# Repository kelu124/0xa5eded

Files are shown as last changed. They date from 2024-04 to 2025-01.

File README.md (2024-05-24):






 





# An 8-bit, 100Msps ADC standalone pHAT

aka 0xA5EDED == sha1(pHATrick)

# Description

An 8-bit, 125Msps ADC standalone pHAT

More? @TODO

# What

__Beware - these need to be updated with actual assembled board. v2 includes sees top going bottom and vice versa.__

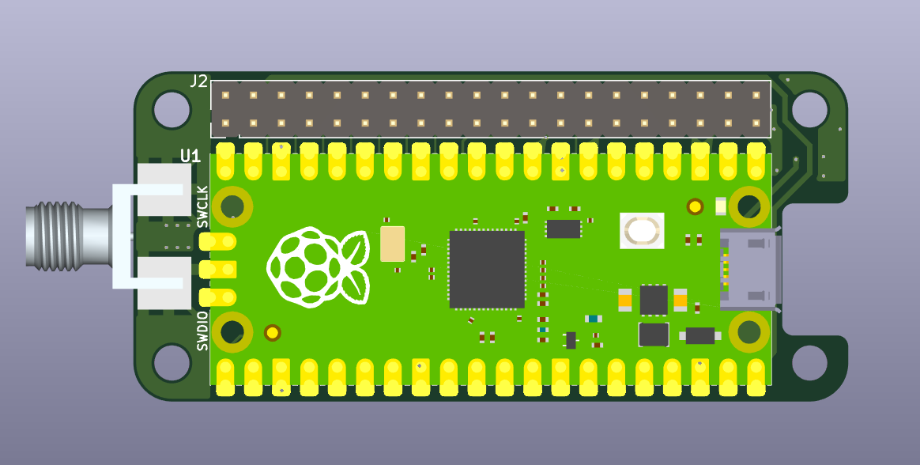
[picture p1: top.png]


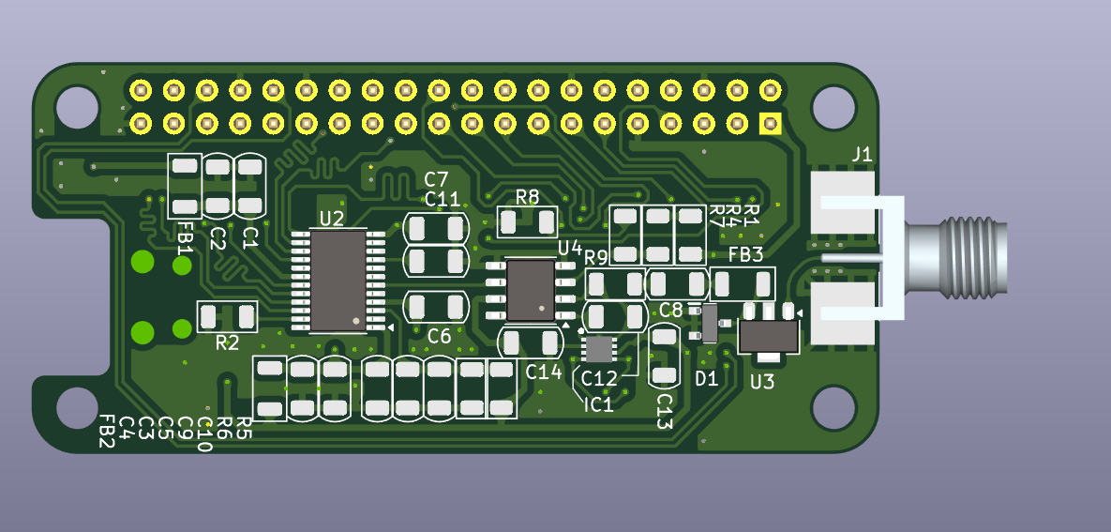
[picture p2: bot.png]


# Acquisition of a square/sine wave

Signal coming out of a cheap DSO, should be around square, 4MHz

### Acquisition 

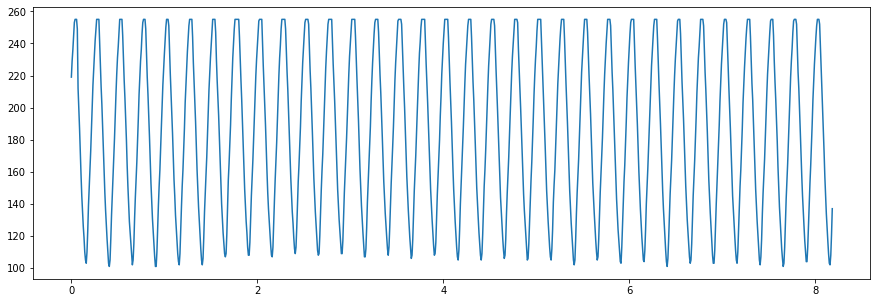
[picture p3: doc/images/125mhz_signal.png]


### Spectrum of a square wave at 125Msps

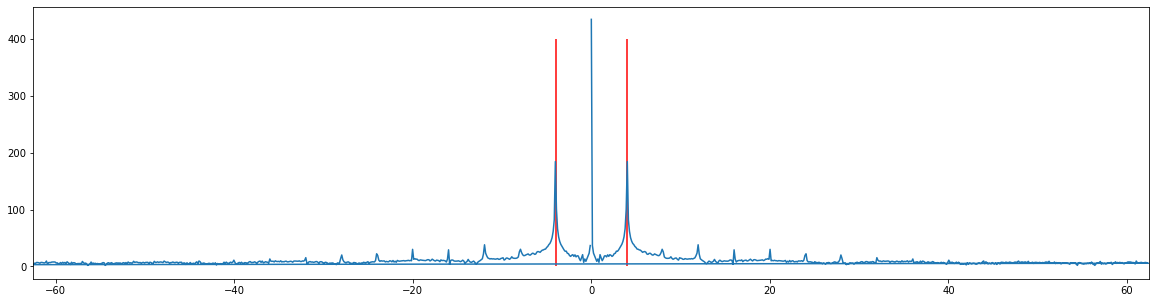
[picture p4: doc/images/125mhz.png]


# Changes from v1

* Remove i2c to something simpler - MCP40D17T
* Let user choose offset or not
* Check OPAMP capa to get a 60MHz cutoff
* BAV / MD0100 to be removed
* Putting the rp2040 under the board, to expose the beautiful art to users

# License

This work is based a previous TAPR exploration, the [pic0rick project](https://github.com/kelu124/pic0rick/) - these open hardware and software, developped with open-source elements as much as possible.

Copyright Luc Jonveaux (kelu124@gmail.com) 2024

* The hardware is licensed under TAPR Open Hardware License (www.tapr.org/OHL)
* The software components are free software: you can redistribute it and/or modify it under the terms of the GNU General Public License as published by the Free Software Foundation, either version 3 of the License, or (at your option) any later version.
* The documentation is licensed under a [Creative Commons Attribution-ShareAlike 3.0 Unported License](http://creativecommons.org/licenses/by-sa/3.0/).

## Disclaimer

This project is distributed WITHOUT ANY EXPRESS OR IMPLIED WARRANTY, INCLUDING OF MERCHANTABILITY, SATISFACTORY QUALITY AND FITNESS FOR A PARTICULAR PURPOSE.

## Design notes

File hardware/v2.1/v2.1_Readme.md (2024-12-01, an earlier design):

# v2.1 : Remarks after prod

## Issues

Prod done on Nov 4th 2024

* Issues with TLV271 (particularily the GND pin)
  * Quick fix by removing TLV271 
  * and shorting pin 3 and 4 (VREF of ADC to output of U10)

* 40pins header issues:
  * Free header pins 26/17 (used in RPi by ID EEPROM), move to other pins
  * Wrong GND pin: move GND from pin 22 to pin 20 (22 isn't ground)
  * Rename GPIO24/GPIO25 on schematics (to the 2 other ADCs)
  * A0 to be to header too

* SDA and SCL are switched. Needs to be corrected.
* Add pullups to the SDA lines, to 3.3V.

## Passive sizes

* Make R16, R8 and R9 1206-sized

## TO ADD

Marking to OSHWA
- https://certification.oshwa.org/fr000022.html
-

## ADC

* Return to 10b ADC : ADC10080

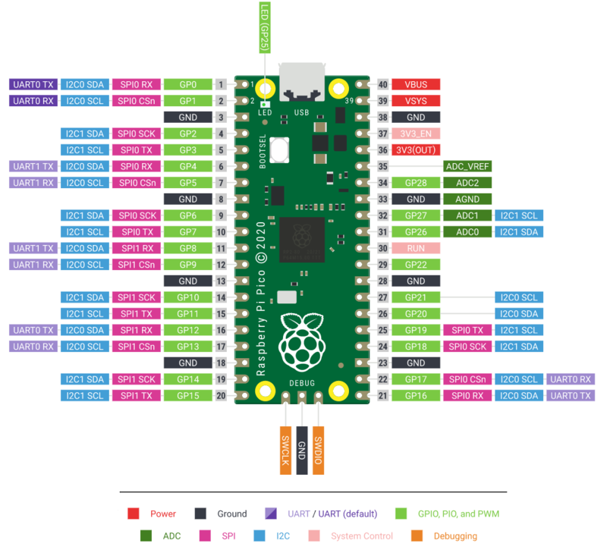
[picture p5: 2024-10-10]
hardware/v2.2b/datasheet/raspberry_pi_Pico-R3-Pinout-narrow.png

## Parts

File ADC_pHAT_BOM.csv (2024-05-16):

Reference | Value | Datasheet | Footprint | Qty | DNP
C1,C3,C4 | 22uF | ~ | Capacitor_SMD_AKL:C_1206_3216Metric | 3
C2,C5,C6,C7,C10,C11,C13,C14 | 100nF | ~ | Capacitor_SMD_AKL:C_1206_3216Metric | 8
C8,C9 | 1uF | ~ | Capacitor_SMD_AKL:C_1206_3216Metric | 2
C12 | 33pF | ~ | Capacitor_SMD_AKL:C_1206_3216Metric | 1
D1 | BAV99-7-F | https://www.diodes.com/assets/Datasheets/ds12007.pdf | SamacSys_Parts:SOT95P240X120-3N | 1
FB1,FB2,FB3 | FerriteBead_Small | ~ | Inductor_SMD_AKL:L_1206_3216Metric | 3
IC1 | MAX5395LATA+T | https://pdfserv.maximintegrated.com/en/ds/MAX5395.pdf | SamacSys_Parts:SON50P200X200X80-9N-D | 1
J1 | Conn_Coaxial | ~ | ICTAMKY_V8:AMPHENOL_132357-11 | 1
J2 | Conn_02x20_Odd_Even | ~ | Connector_PinHeader_2.54mm:PinHeader_2x20_P2.54mm_Vertical | 1
R1,R5,R7 | 110 | ~ | Resistor_SMD_AKL:R_1206_3216Metric | 3
R2 | 10K | ~ | Resistor_SMD_AKL:R_1206_3216Metric | 1
R4,R6 | 220 | ~ | Resistor_SMD_AKL:R_1206_3216Metric | 2
R8 | 56 | ~ | Resistor_SMD_AKL:R_1206_3216Metric | 1
R9 | 1K | ~ | Resistor_SMD_AKL:R_1206_3216Metric | 1
U1 | Pico |  | ICTAMKY_V8:RPi_Pico_SMD | 1
U2 | ADC08100CIMTCX/NOPB(TSSOP-24) |  | Package_SO:TSSOP-24_4.4x7.8mm_P0.65mm | 1
U3 | MD0100N8-G | MD0100N8-G | Package_TO_SOT_SMD:SOT-89-3 | 1
U4 | LTC6228xS8 | https://www.analog.com/media/en/technical-documentation/data-sheets/LTC6228-6229.pdf | Package_SO:SO-8_3.9x4.9mm_P1.27mm | 1

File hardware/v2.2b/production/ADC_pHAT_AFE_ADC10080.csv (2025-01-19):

Id | Designator | Footprint | Quantity | Designation | Supplier and ref
1 | U2 | SOT-23 | 1 | LM4040DBZ-2.0
2 | R2,R19,R18,R17 | R_0603_1608Metric | 4 | 1K
3 | C15 | C_0603_1608Metric | 1 | 4.7u
4 | D3,D2,D1 | D_0603_1608Metric | 3 | D
5 | C13,C8,C12,C14 | C_0603_1608Metric | 4 | 2.2u
6 | R11,R14,R13 | R_0603_1608Metric | 3 | 100
7 | C9,C3,C7,C2,C6,C10,C5 | R_0603_1608Metric | 7 | 100nF
8 | R3,R1 | R_0603_1608Metric | 2 | 87k
9 | R5,R6 | R_0603_1608Metric | 2 | 10K
10 | U8 | SOT-23-6 | 1 | DAC5571
11 | U3 | WSON-12-1EP_3x2mm_P0.5mm_EP1x2.65_ThermalVias | 1 | LM27762
12 | J3 | AMPHENOL_132357-11-MOD | 1 | Conn_Coaxial
13 | FB2,FB1 | L_1206_3216Metric | 2 | FerriteBead_Small
14 | U4 | MSOP-10_3x3mm_P0.5mm | 1 | ADG621
15 | C18 | C_0603_1608Metric | 1 | 1p
16 | IC1 | SOP65P640X120-28N | 1 | ADC10080CIMT_NOPB
17 | C1,C4 | R_0603_1608Metric | 2 | 4.7uF
18 | R8 | R_1206_3216Metric | 1 | 47
19 | C23 | C_0603_1608Metric | 1 | 160p
20 | R12 | R_0603_1608Metric | 1 | 680k
21 | C21 | C_0603_1608Metric | 1 | 10n
22 | R7,R4 | R_0603_1608Metric | 2 | 50K
23 | C22 | C_0603_1608Metric | 1 | 6.8p
24 | C17,C20,C19,C16,C24 | C_0603_1608Metric | 5 | 100n
25 | R9,R16 | R_1206_3216Metric | 2 | 100
26 | J1 | PinHeader_1x02_P1.00mm_Vertical_SMD_Pin1Left | 1 | Conn_01x02_Male
27 | U6 | SOT-23-5 | 1 | TPH2501
28 | R10 | R_0603_1608Metric | 1 | 680
29 | U5 | SOT-23-5 | 1 | OPA830
30 | R15 | R_0603_1608Metric | 1 | 100k
31 | U7 | SOT-23-5 | 1 | LMH6629
32 | J2 | PinSocket_2x20_P2.54mm_Vertical | 1 | Conn_02x20_Odd_Even
33 | U1 | RPi_Pico_SMD | 1 | Pico

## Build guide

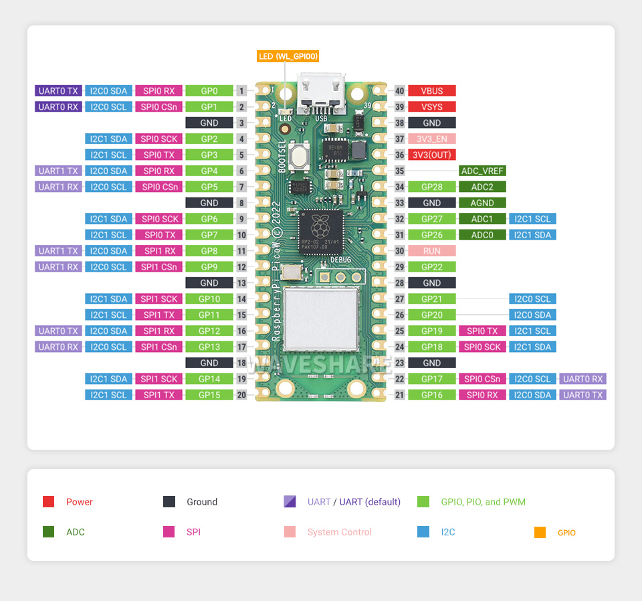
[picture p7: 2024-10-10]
hardware/v2.2b/datasheet/Raspberry_Pi_Pico_W_Manual01.jpg

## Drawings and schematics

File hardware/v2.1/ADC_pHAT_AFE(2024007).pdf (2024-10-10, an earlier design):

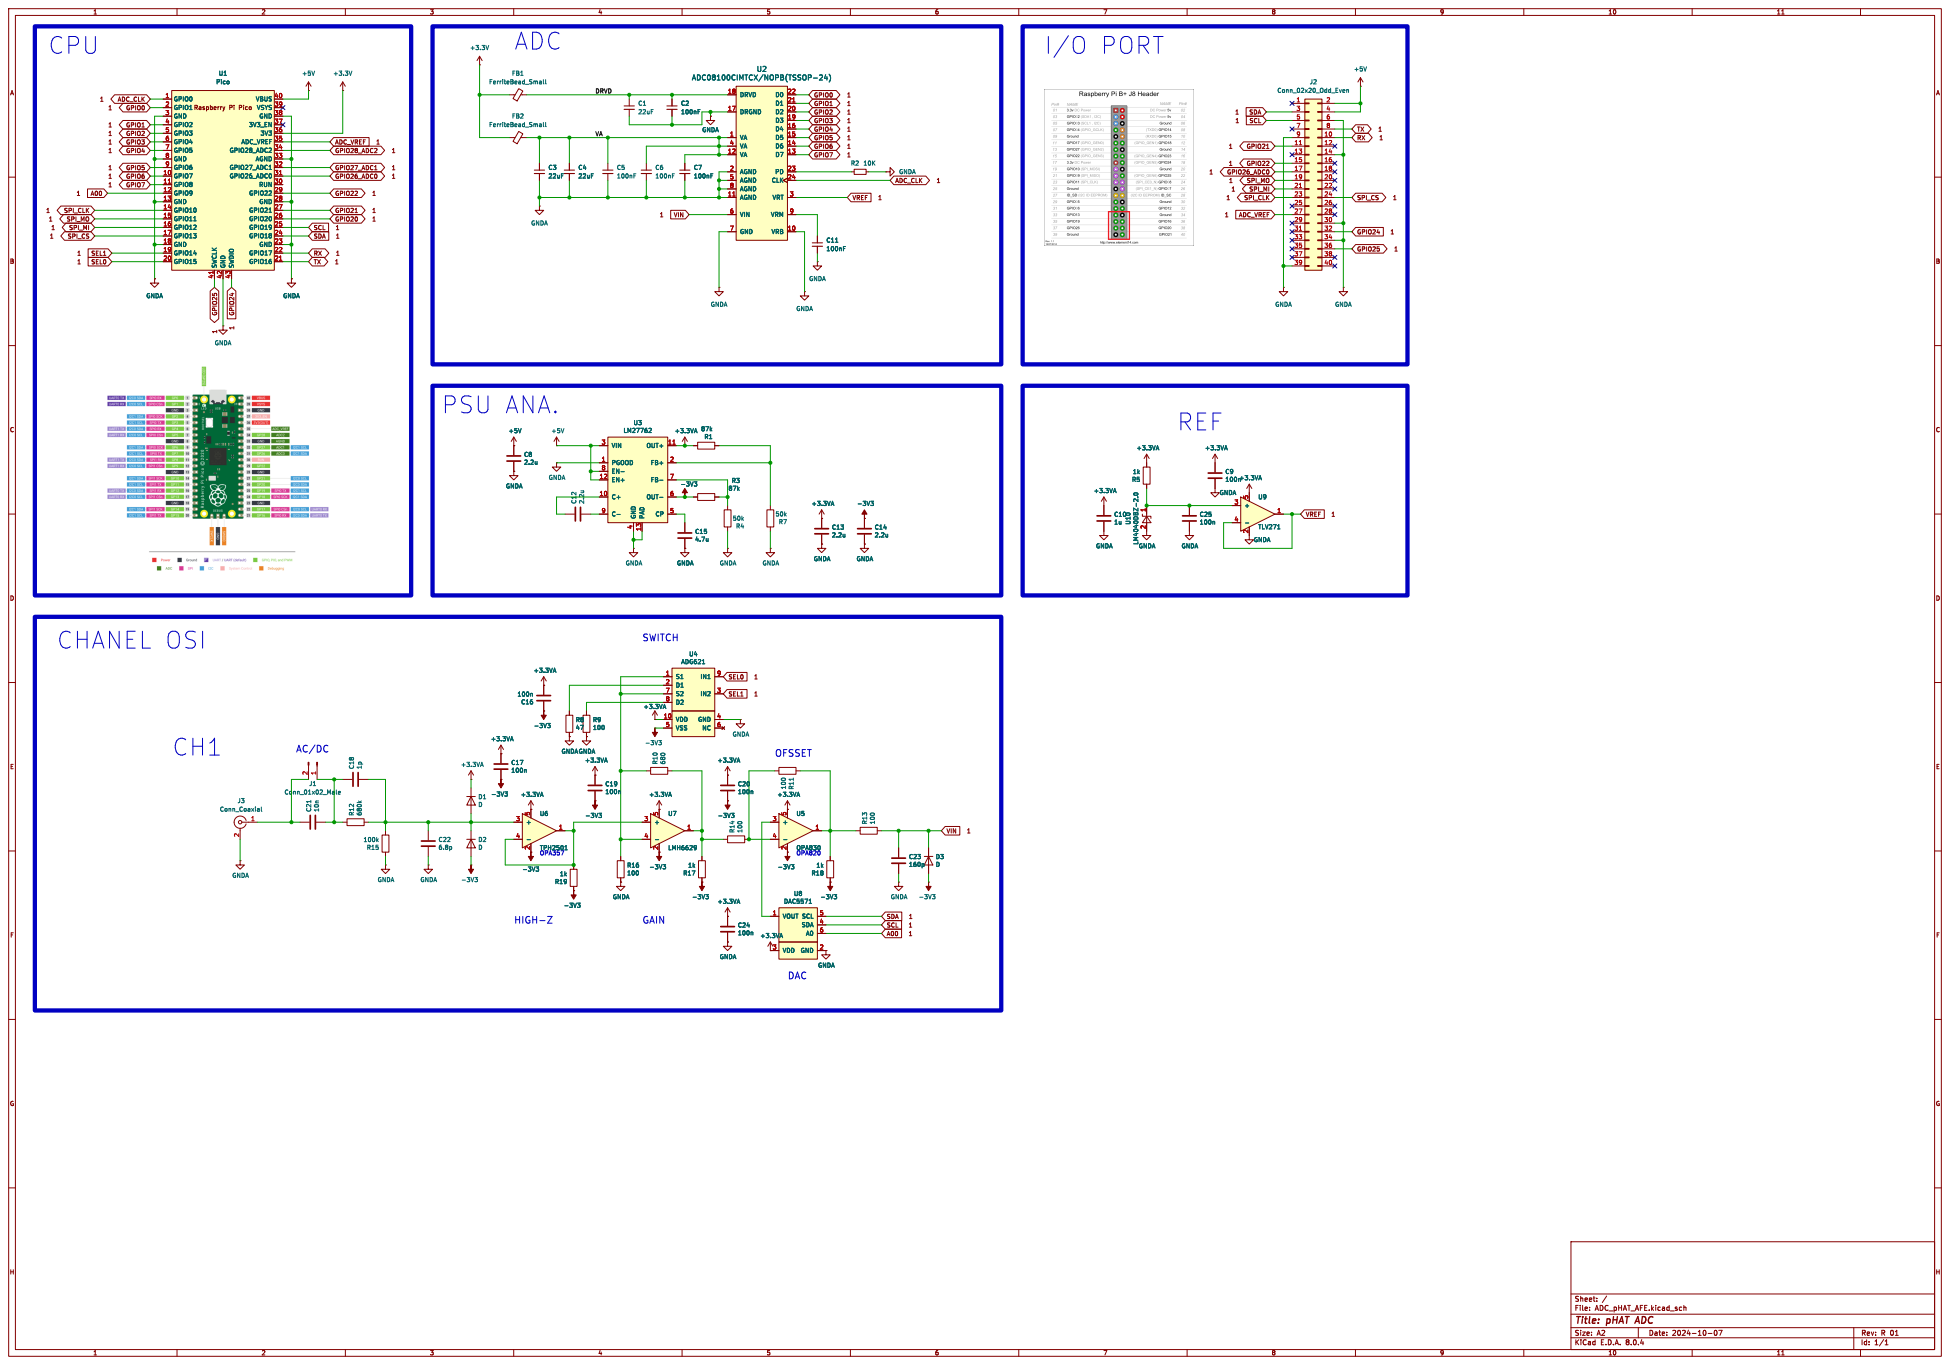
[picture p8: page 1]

4 CP 5 OUT- 6 FB- 7 EN- 8 C- 9 GNDA U1 Pico GPIO0 1 GPIO7 10 GPIO8 11 GPIO9 12 GND 13 GPIO10 14 GPIO11 15 GPIO12 16 GPIO13 17 GND 18 GPIO14 19 GPIO1 2 GPIO15 20 GPIO16 21 GPIO17 22 GND 23 GPIO18 24 GPIO19 25 GPIO20 26 GPIO21 27 GND 28 GPIO22 29 GND 3 RUN 30 GPIO26_ADC0 31 GPIO27_ADC1 32 AGND 33 GPIO28_ADC2 34 ADC_VREF 35

4 CP 5 OUT- 6 FB- 7 EN- 8 C- 9 U3

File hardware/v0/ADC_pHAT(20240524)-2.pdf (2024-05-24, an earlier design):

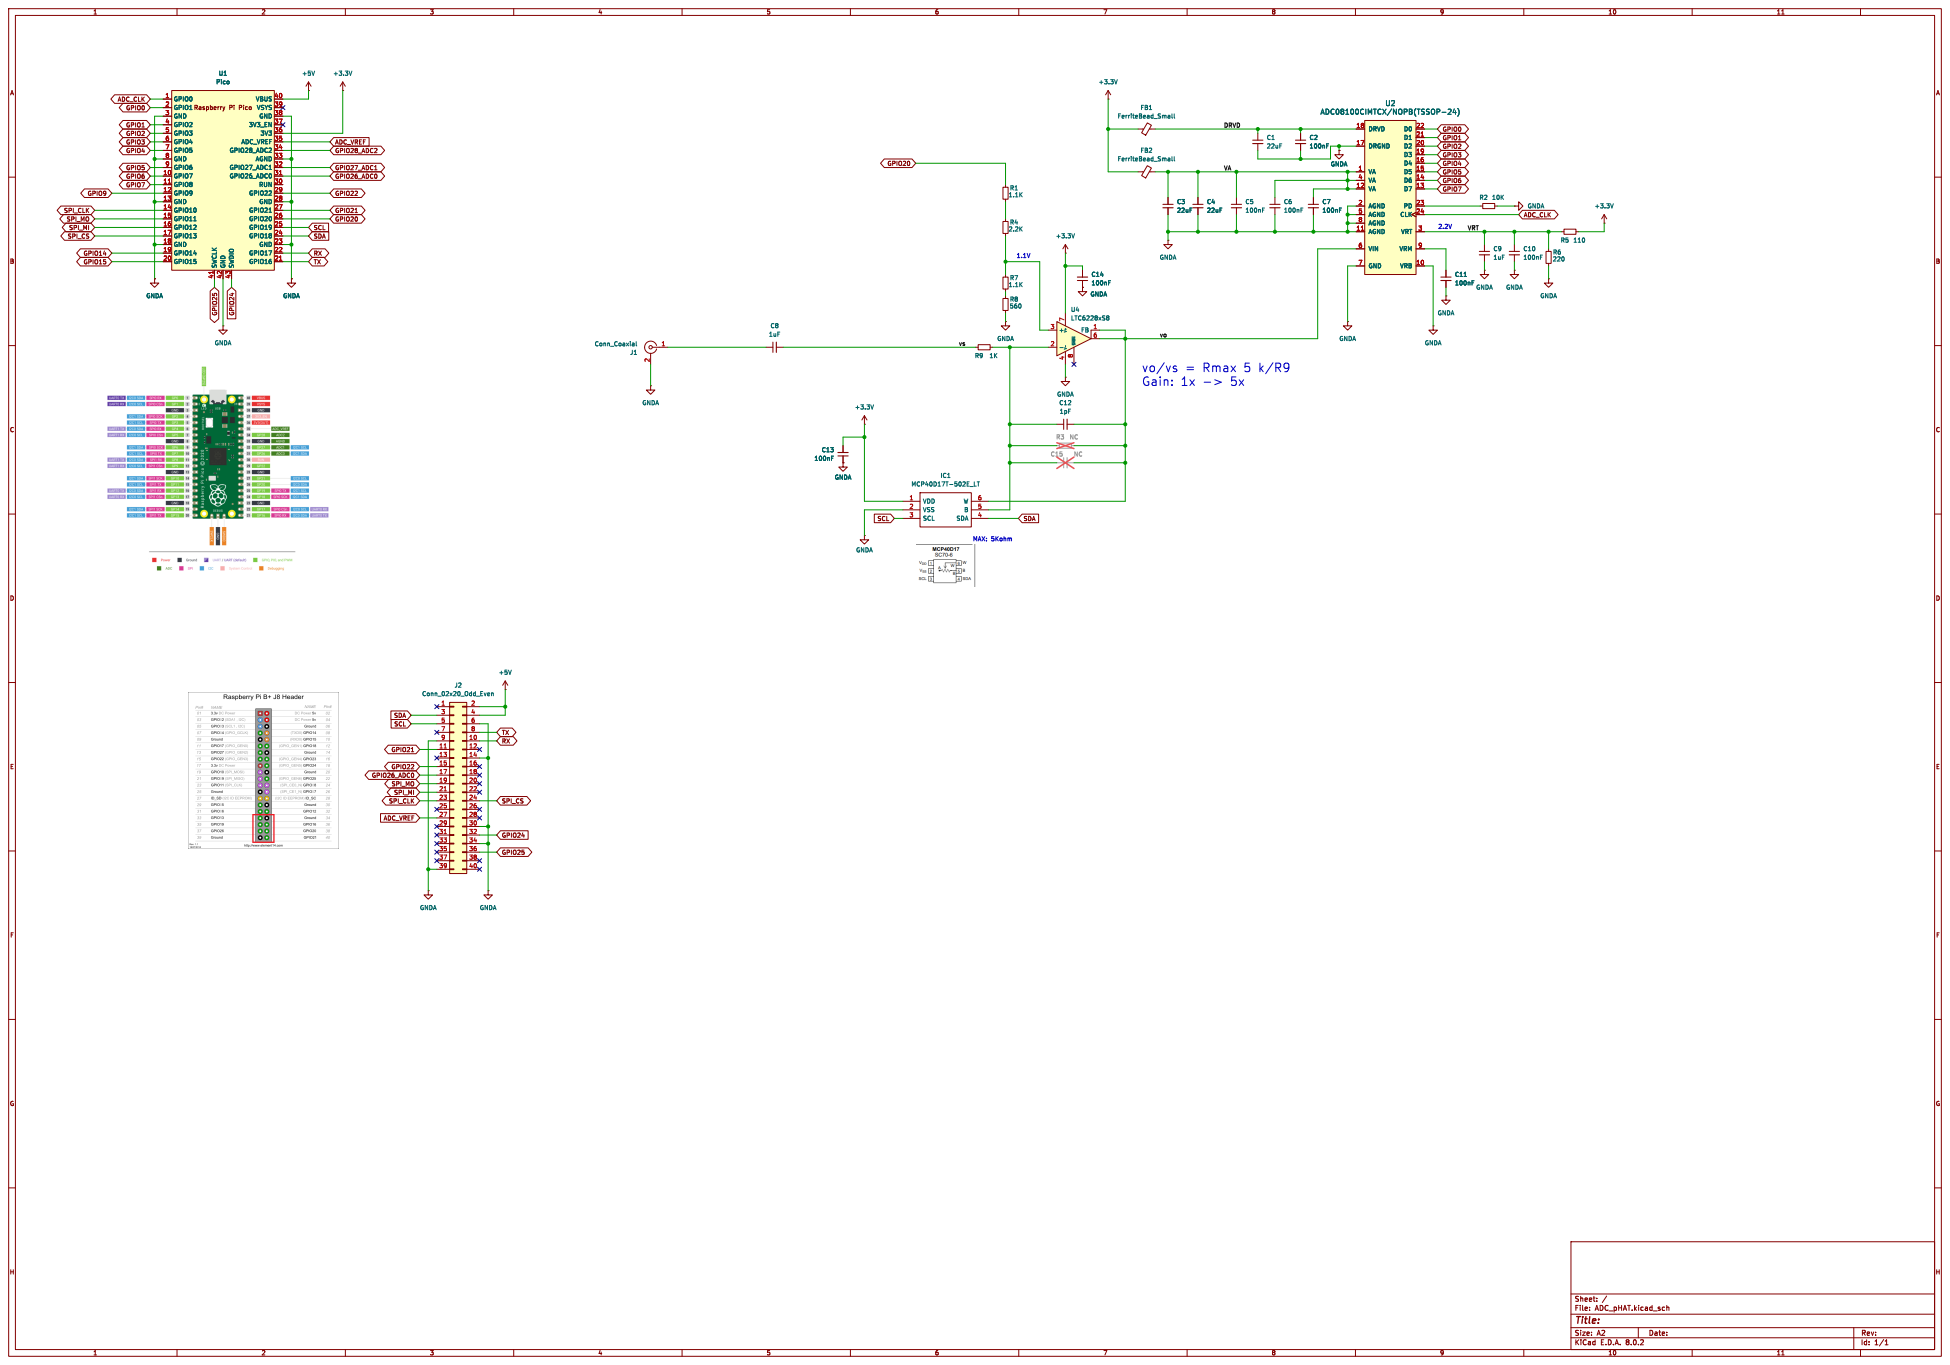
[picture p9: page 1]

220 GNDA GNDA GNDA GNDA

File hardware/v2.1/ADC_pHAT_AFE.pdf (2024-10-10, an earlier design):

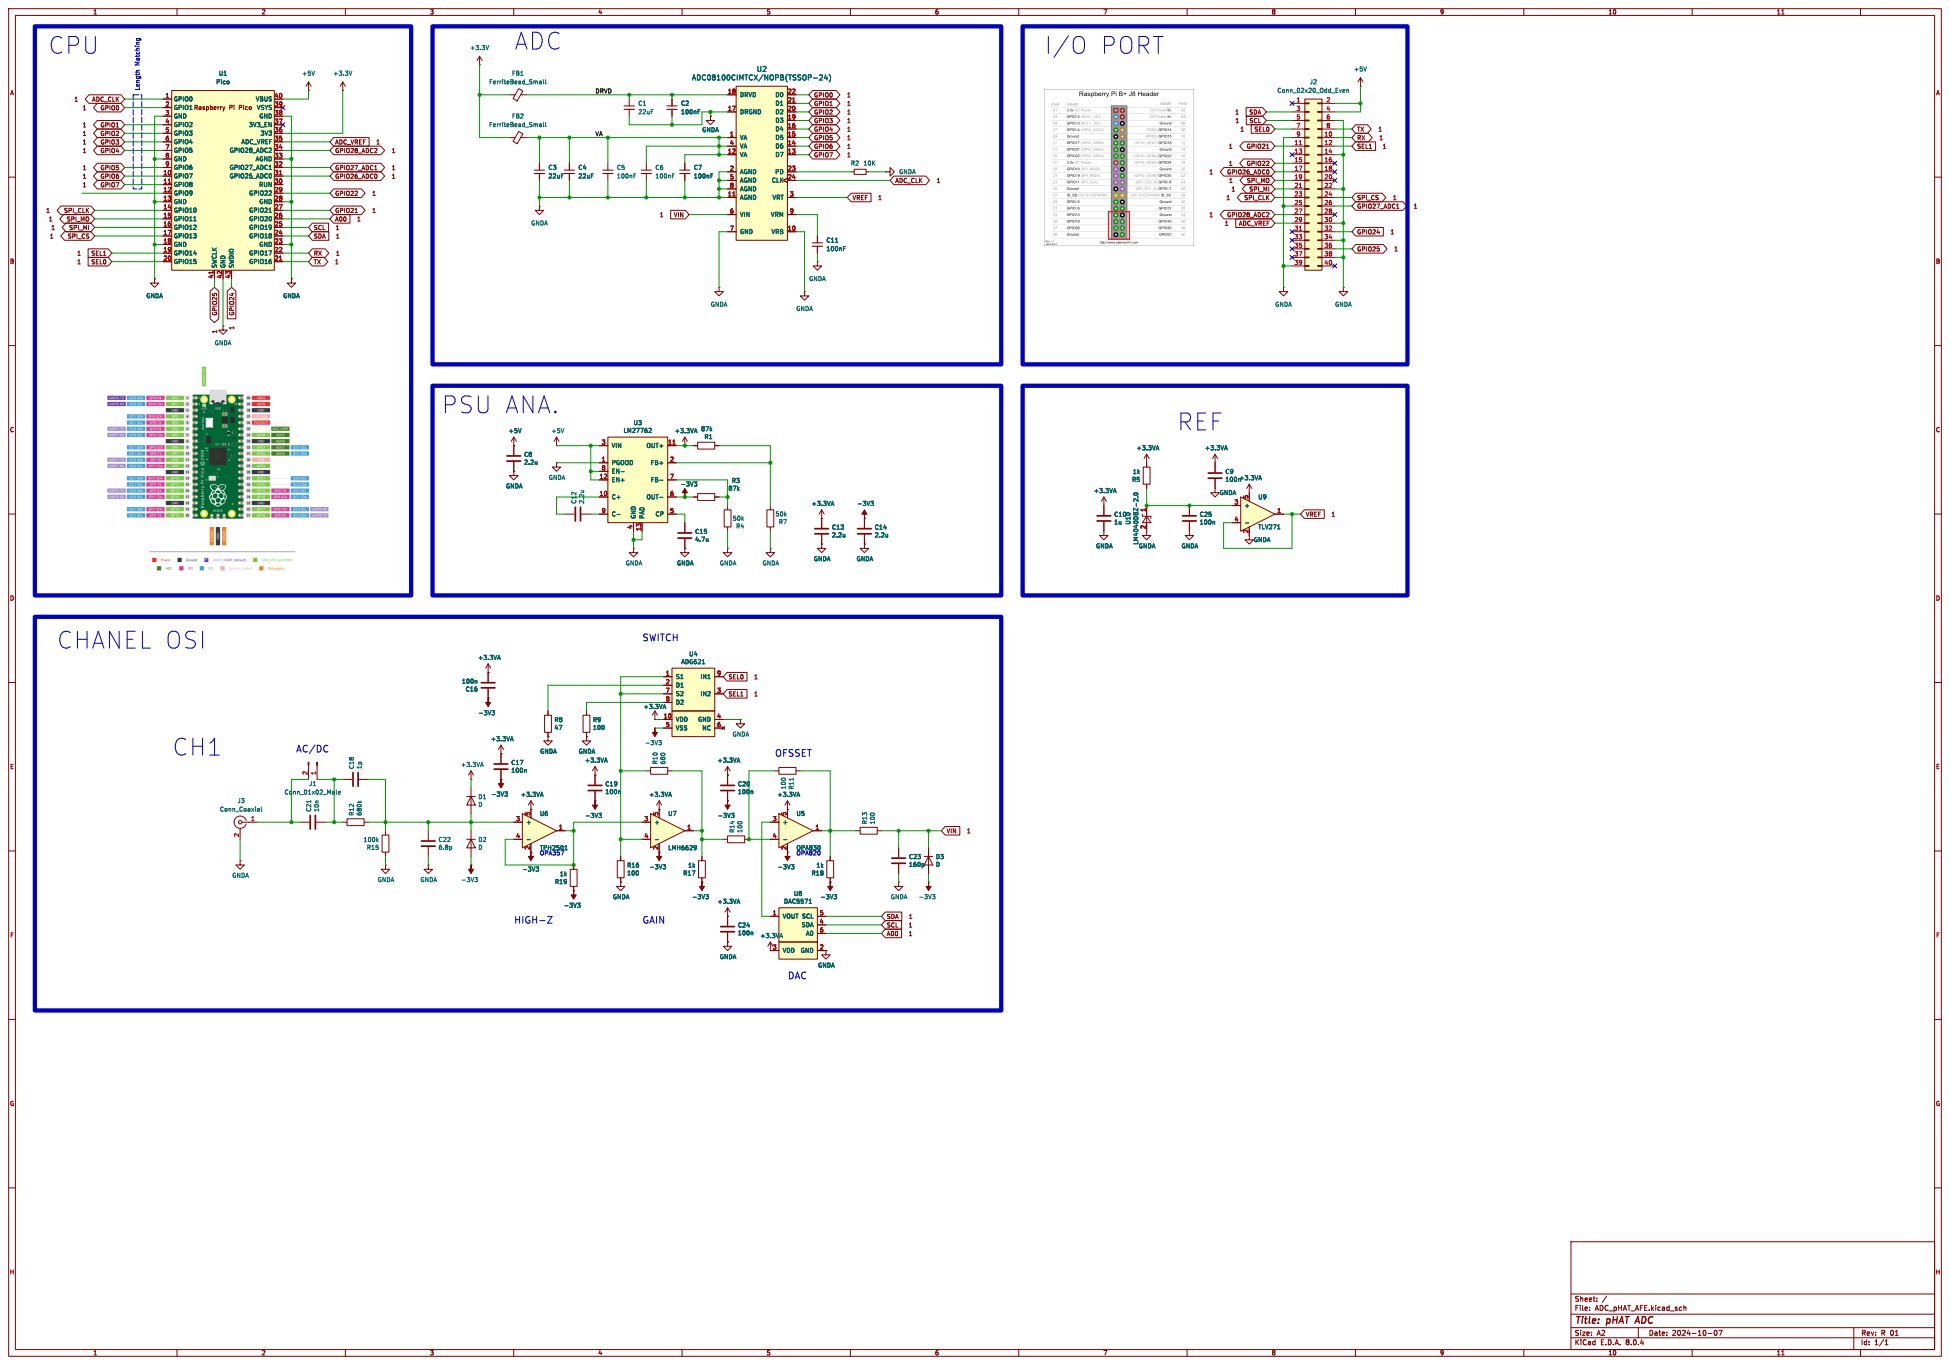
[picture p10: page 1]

4 CP 5 OUT- 6 FB- 7 EN- 8 C- 9 U3

4 CP 5 OUT- 6 FB- 7 EN- 8 C- 9 U4 ADG621 S1 1 VDD 10 D1 2

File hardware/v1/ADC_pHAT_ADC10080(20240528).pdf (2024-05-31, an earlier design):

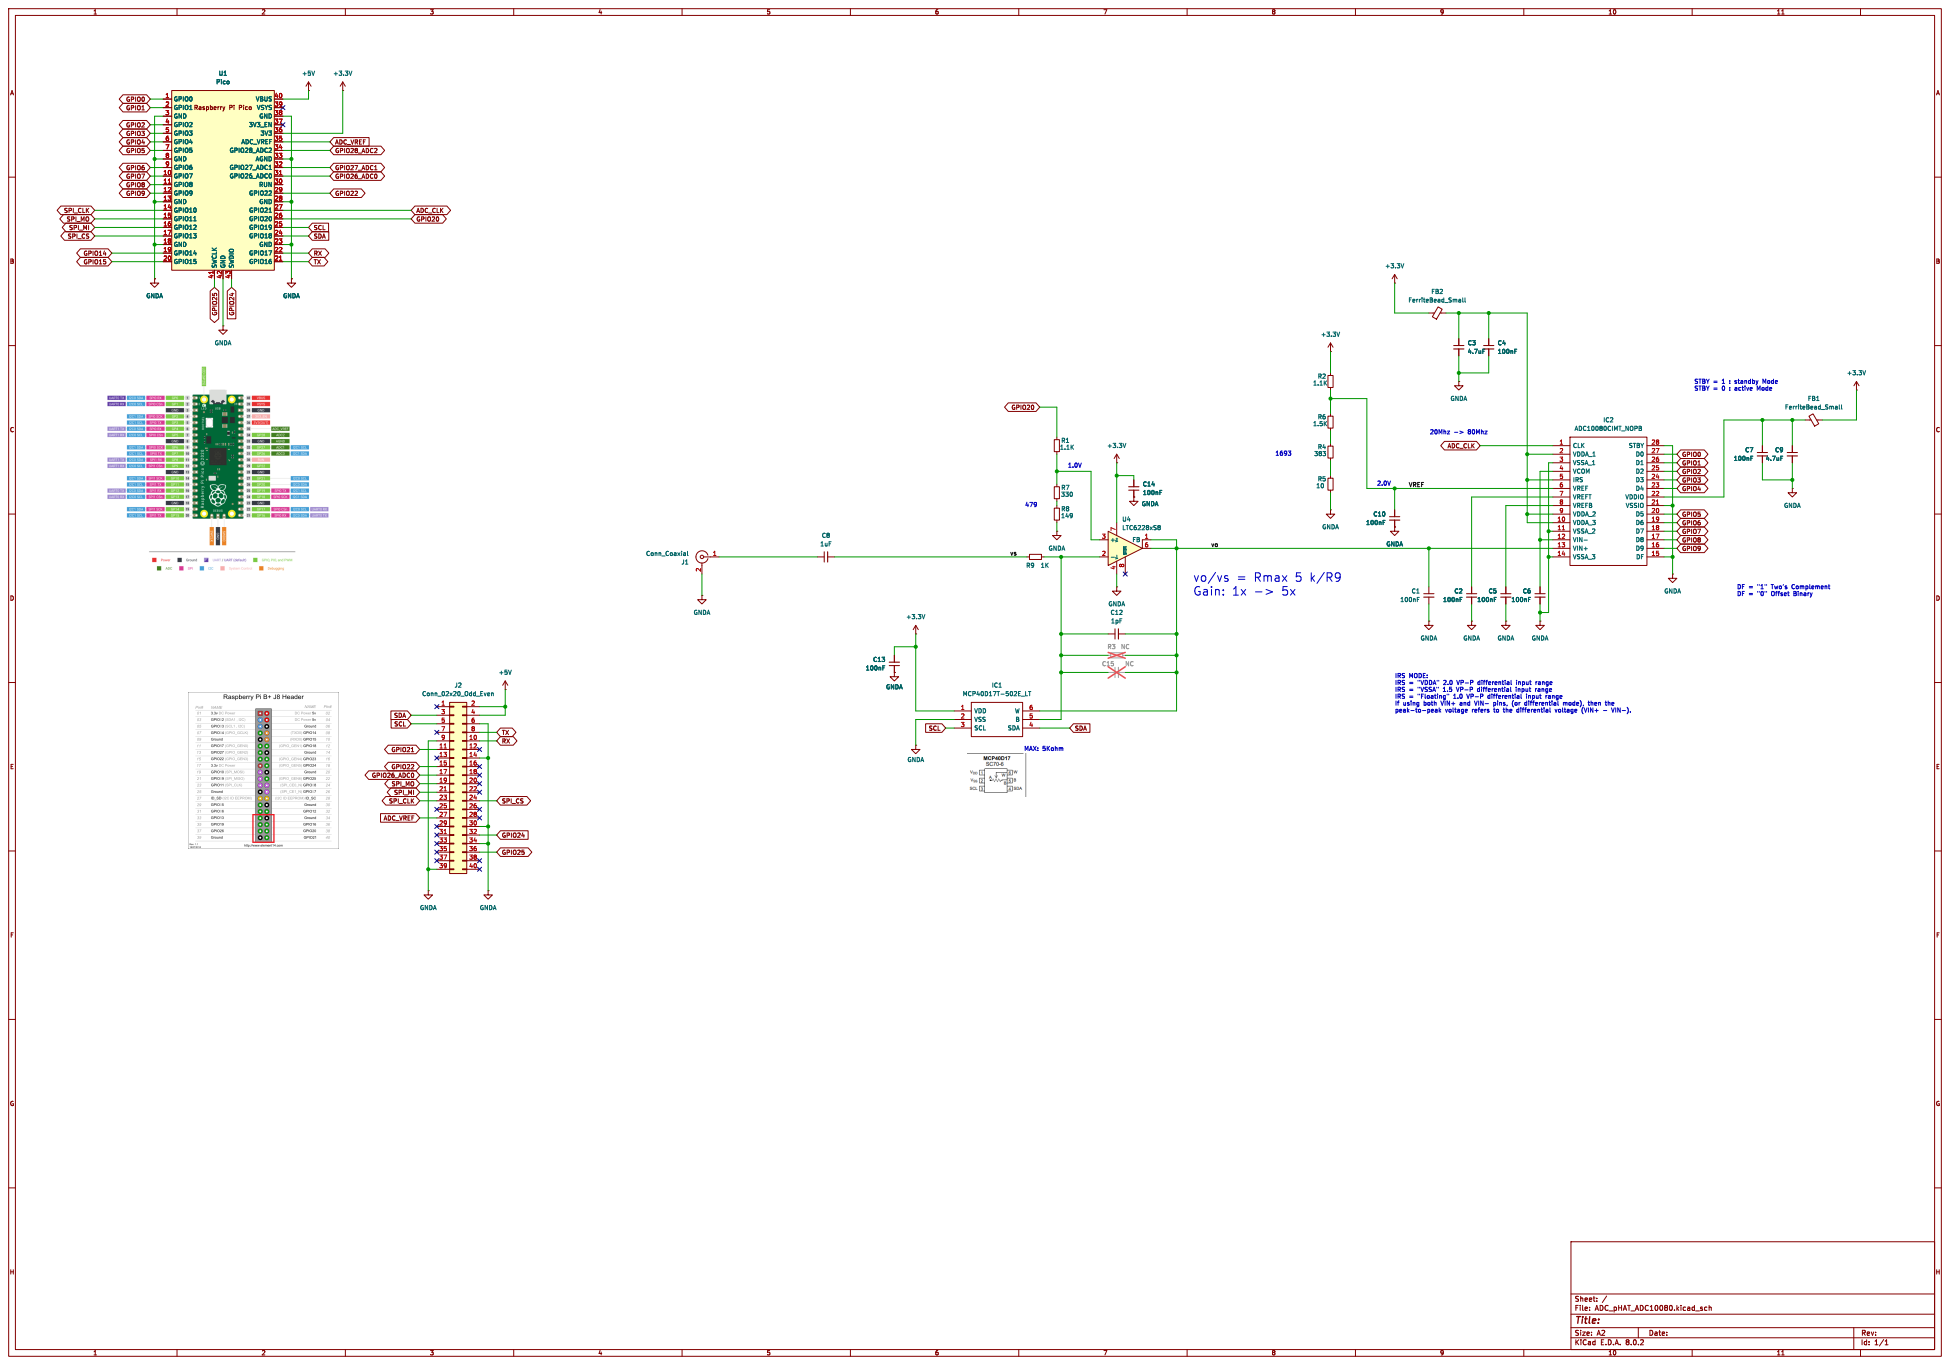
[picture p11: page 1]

STBY = 1 : standby Mode STBY = 0 : active Mode

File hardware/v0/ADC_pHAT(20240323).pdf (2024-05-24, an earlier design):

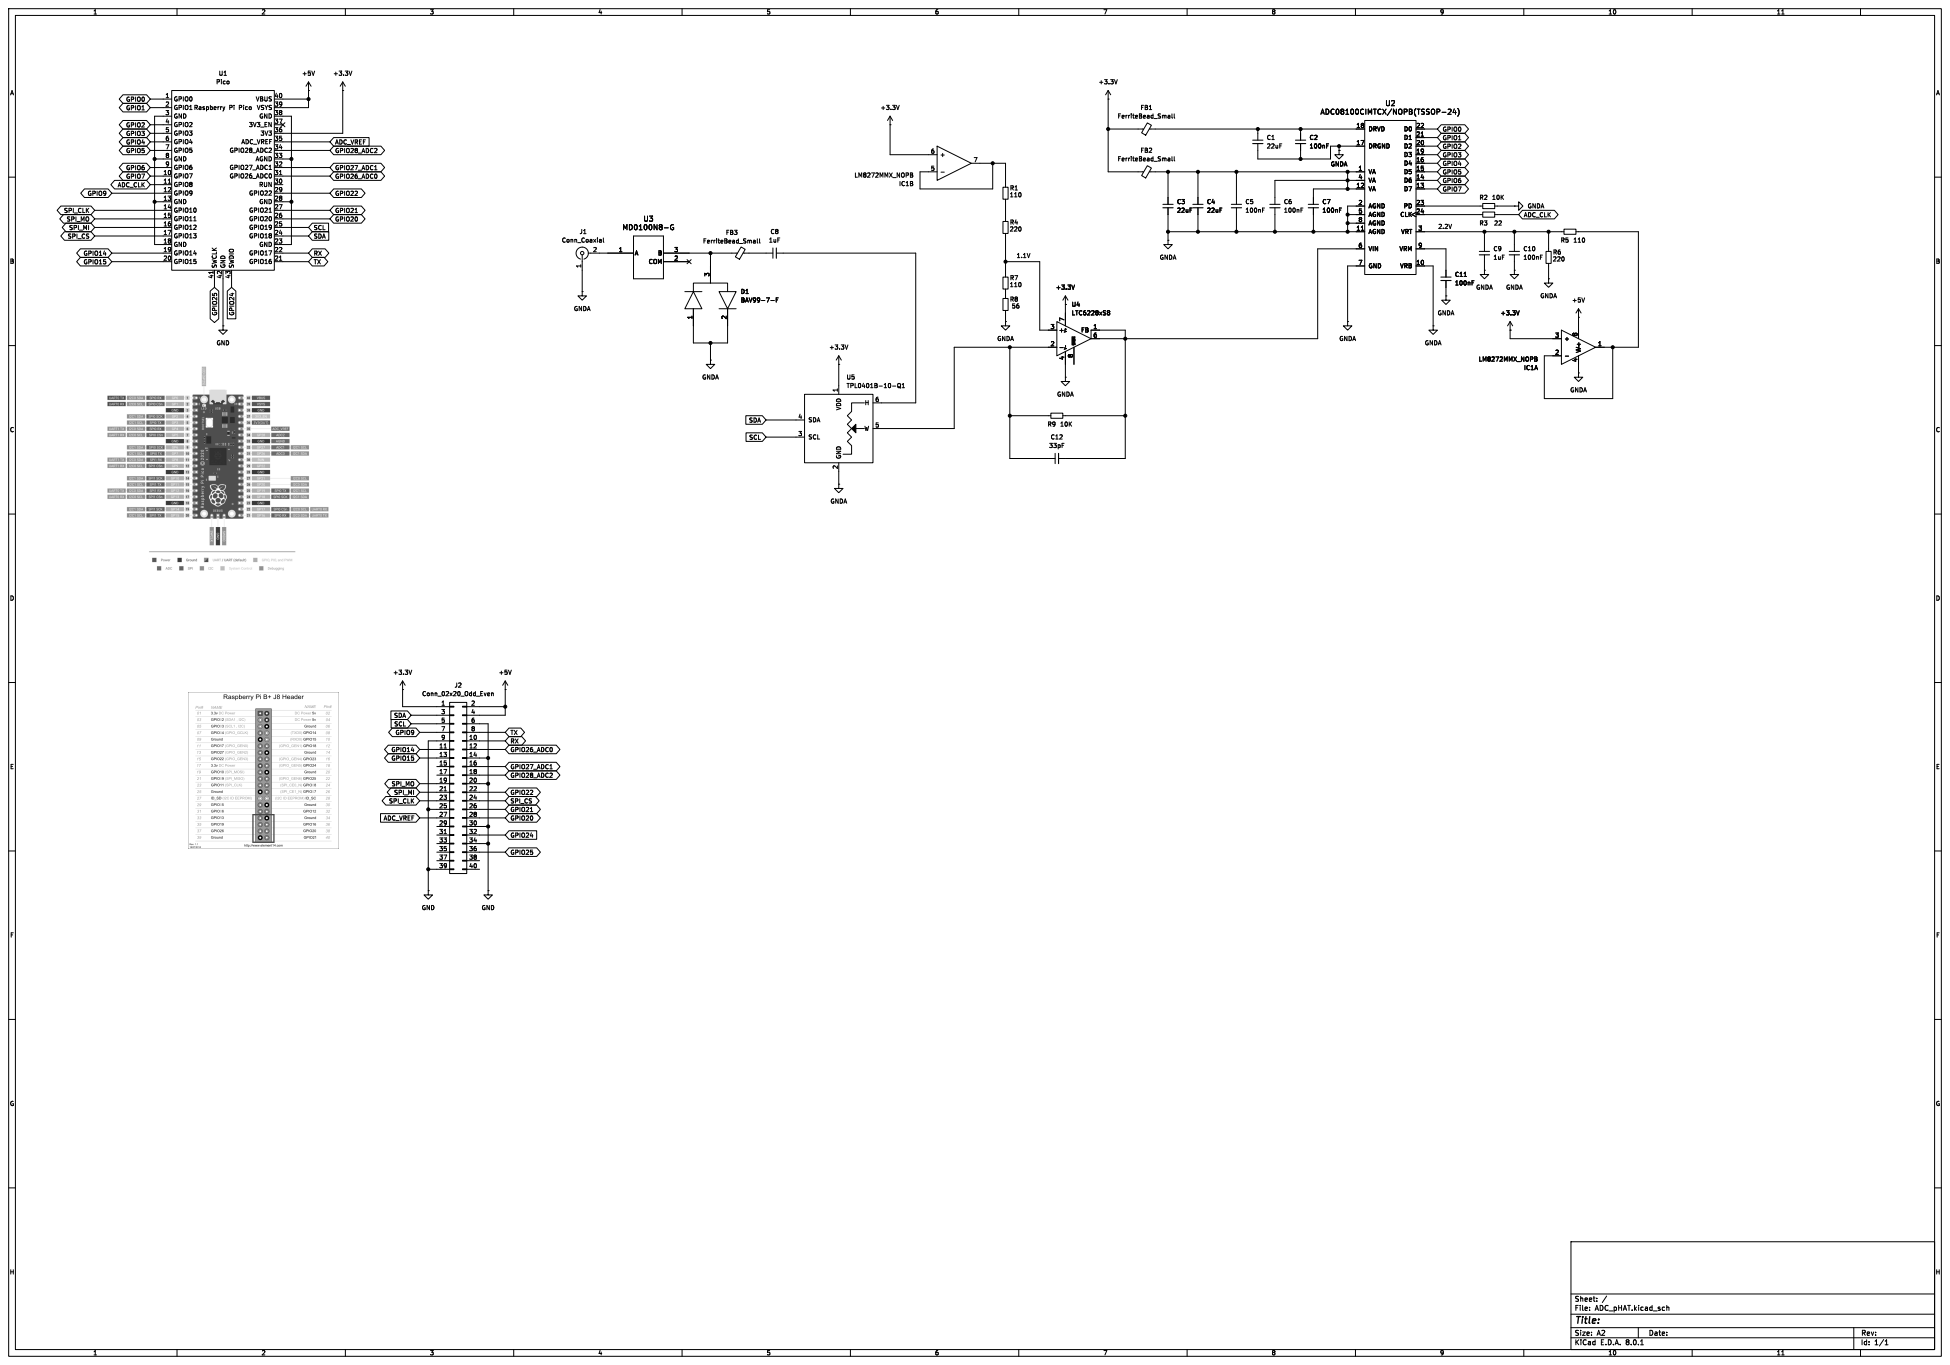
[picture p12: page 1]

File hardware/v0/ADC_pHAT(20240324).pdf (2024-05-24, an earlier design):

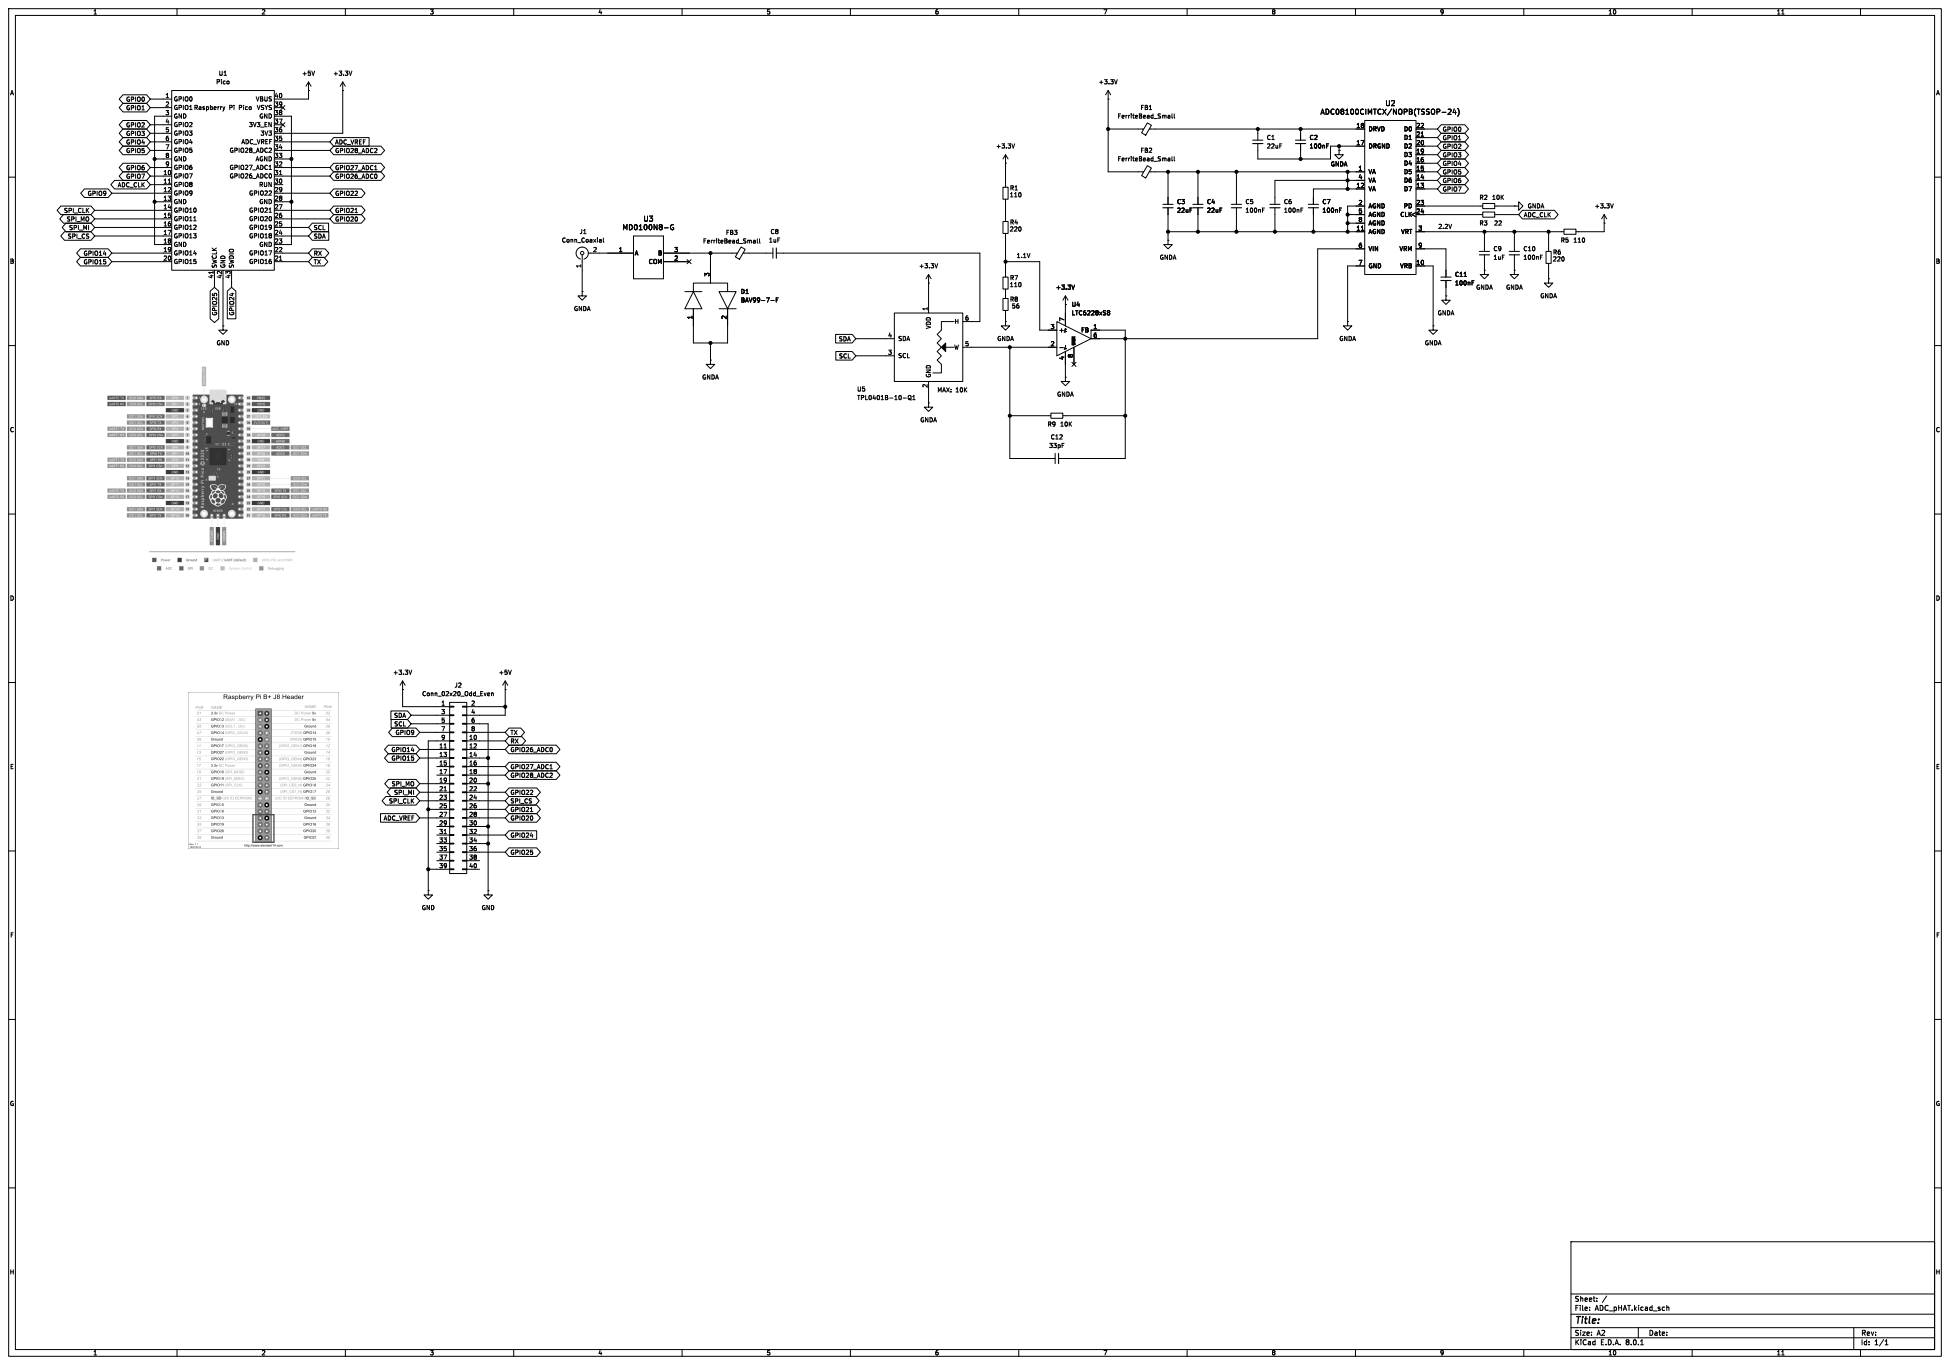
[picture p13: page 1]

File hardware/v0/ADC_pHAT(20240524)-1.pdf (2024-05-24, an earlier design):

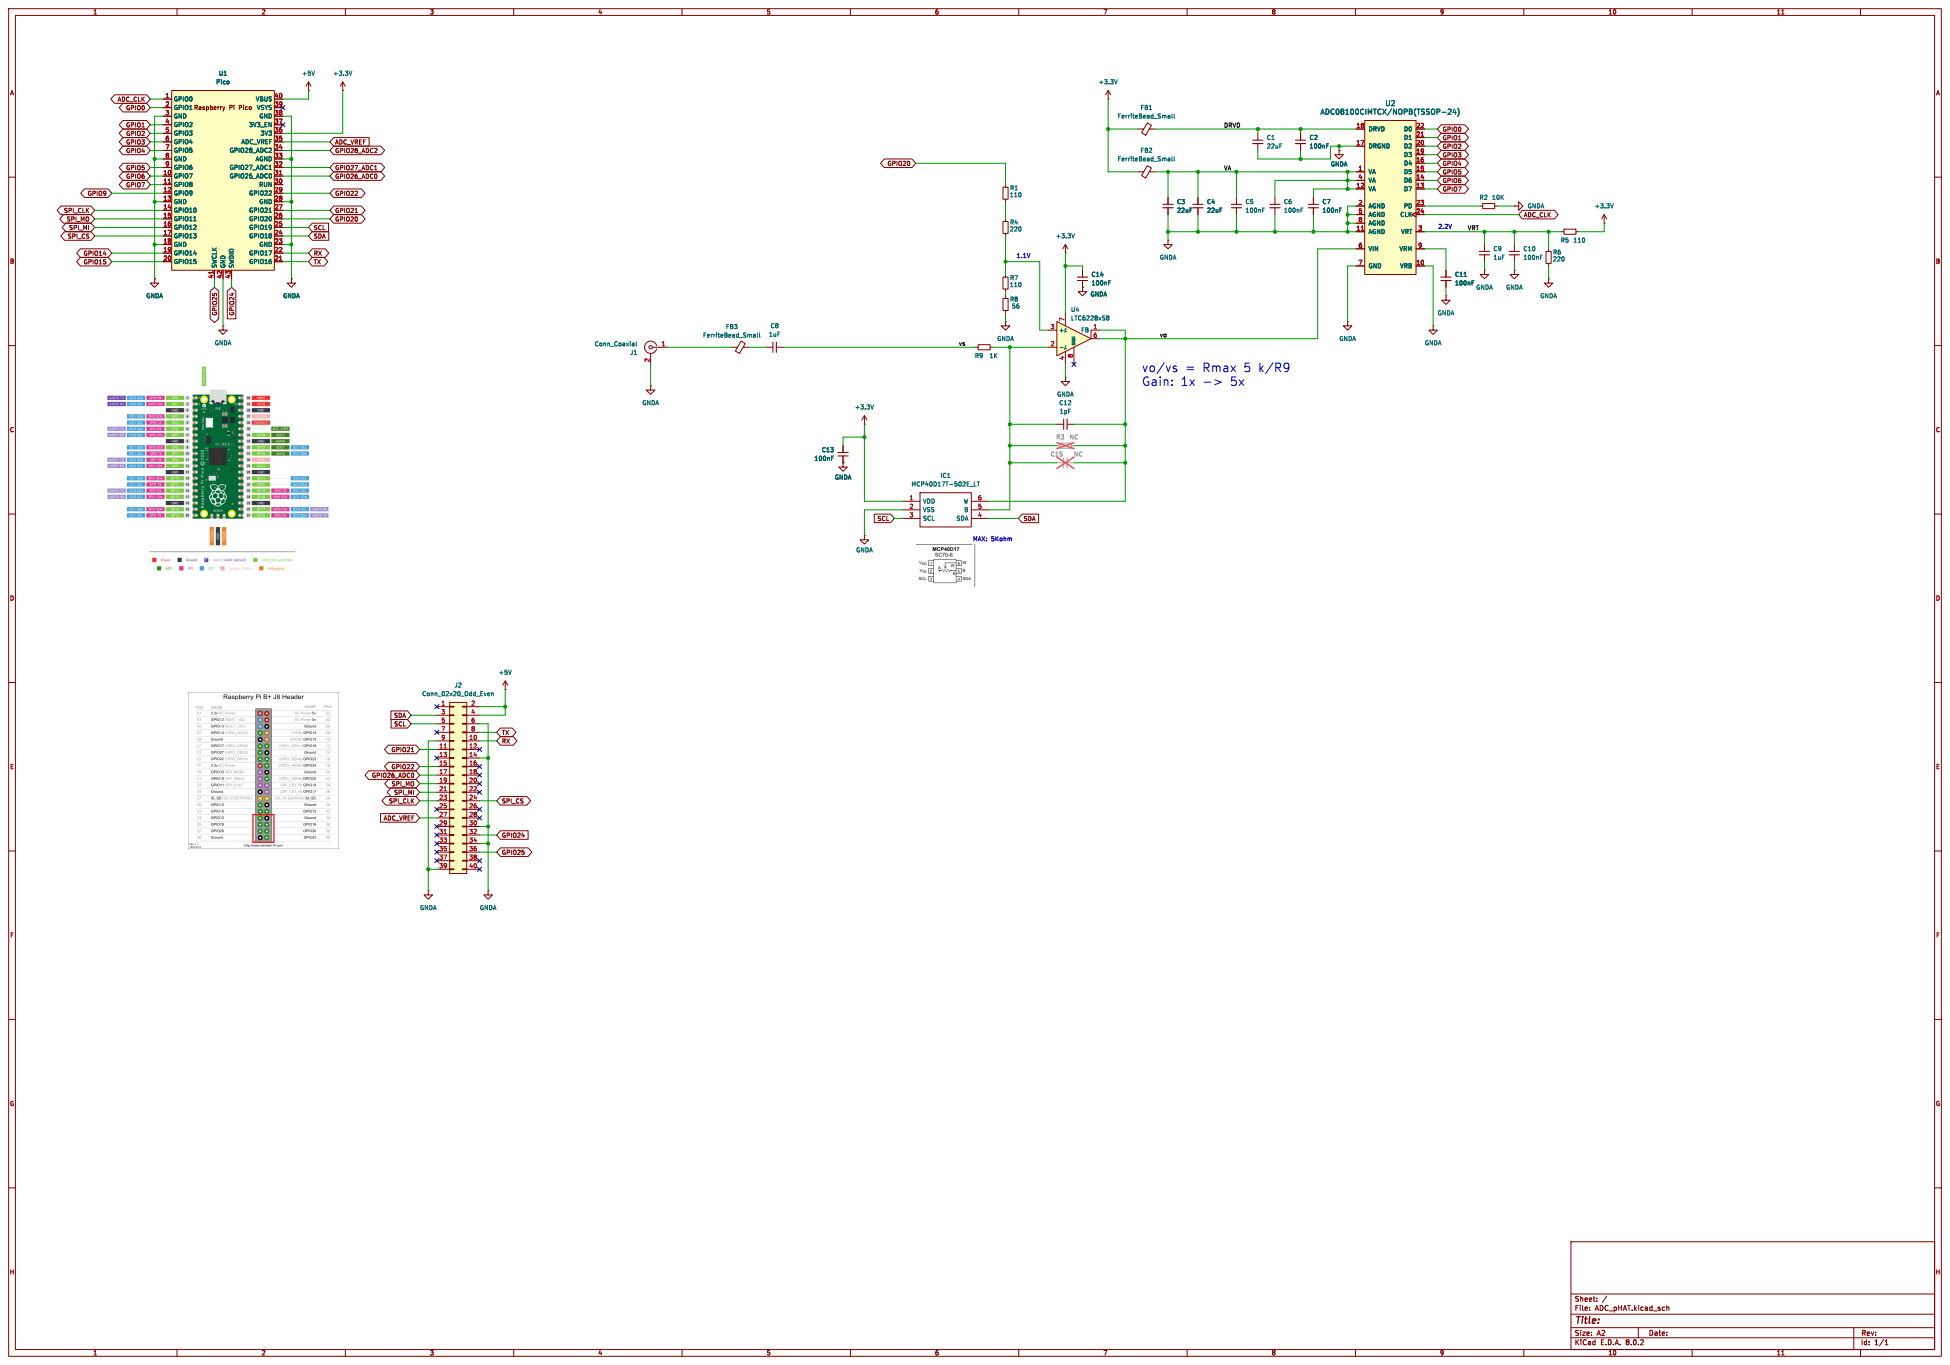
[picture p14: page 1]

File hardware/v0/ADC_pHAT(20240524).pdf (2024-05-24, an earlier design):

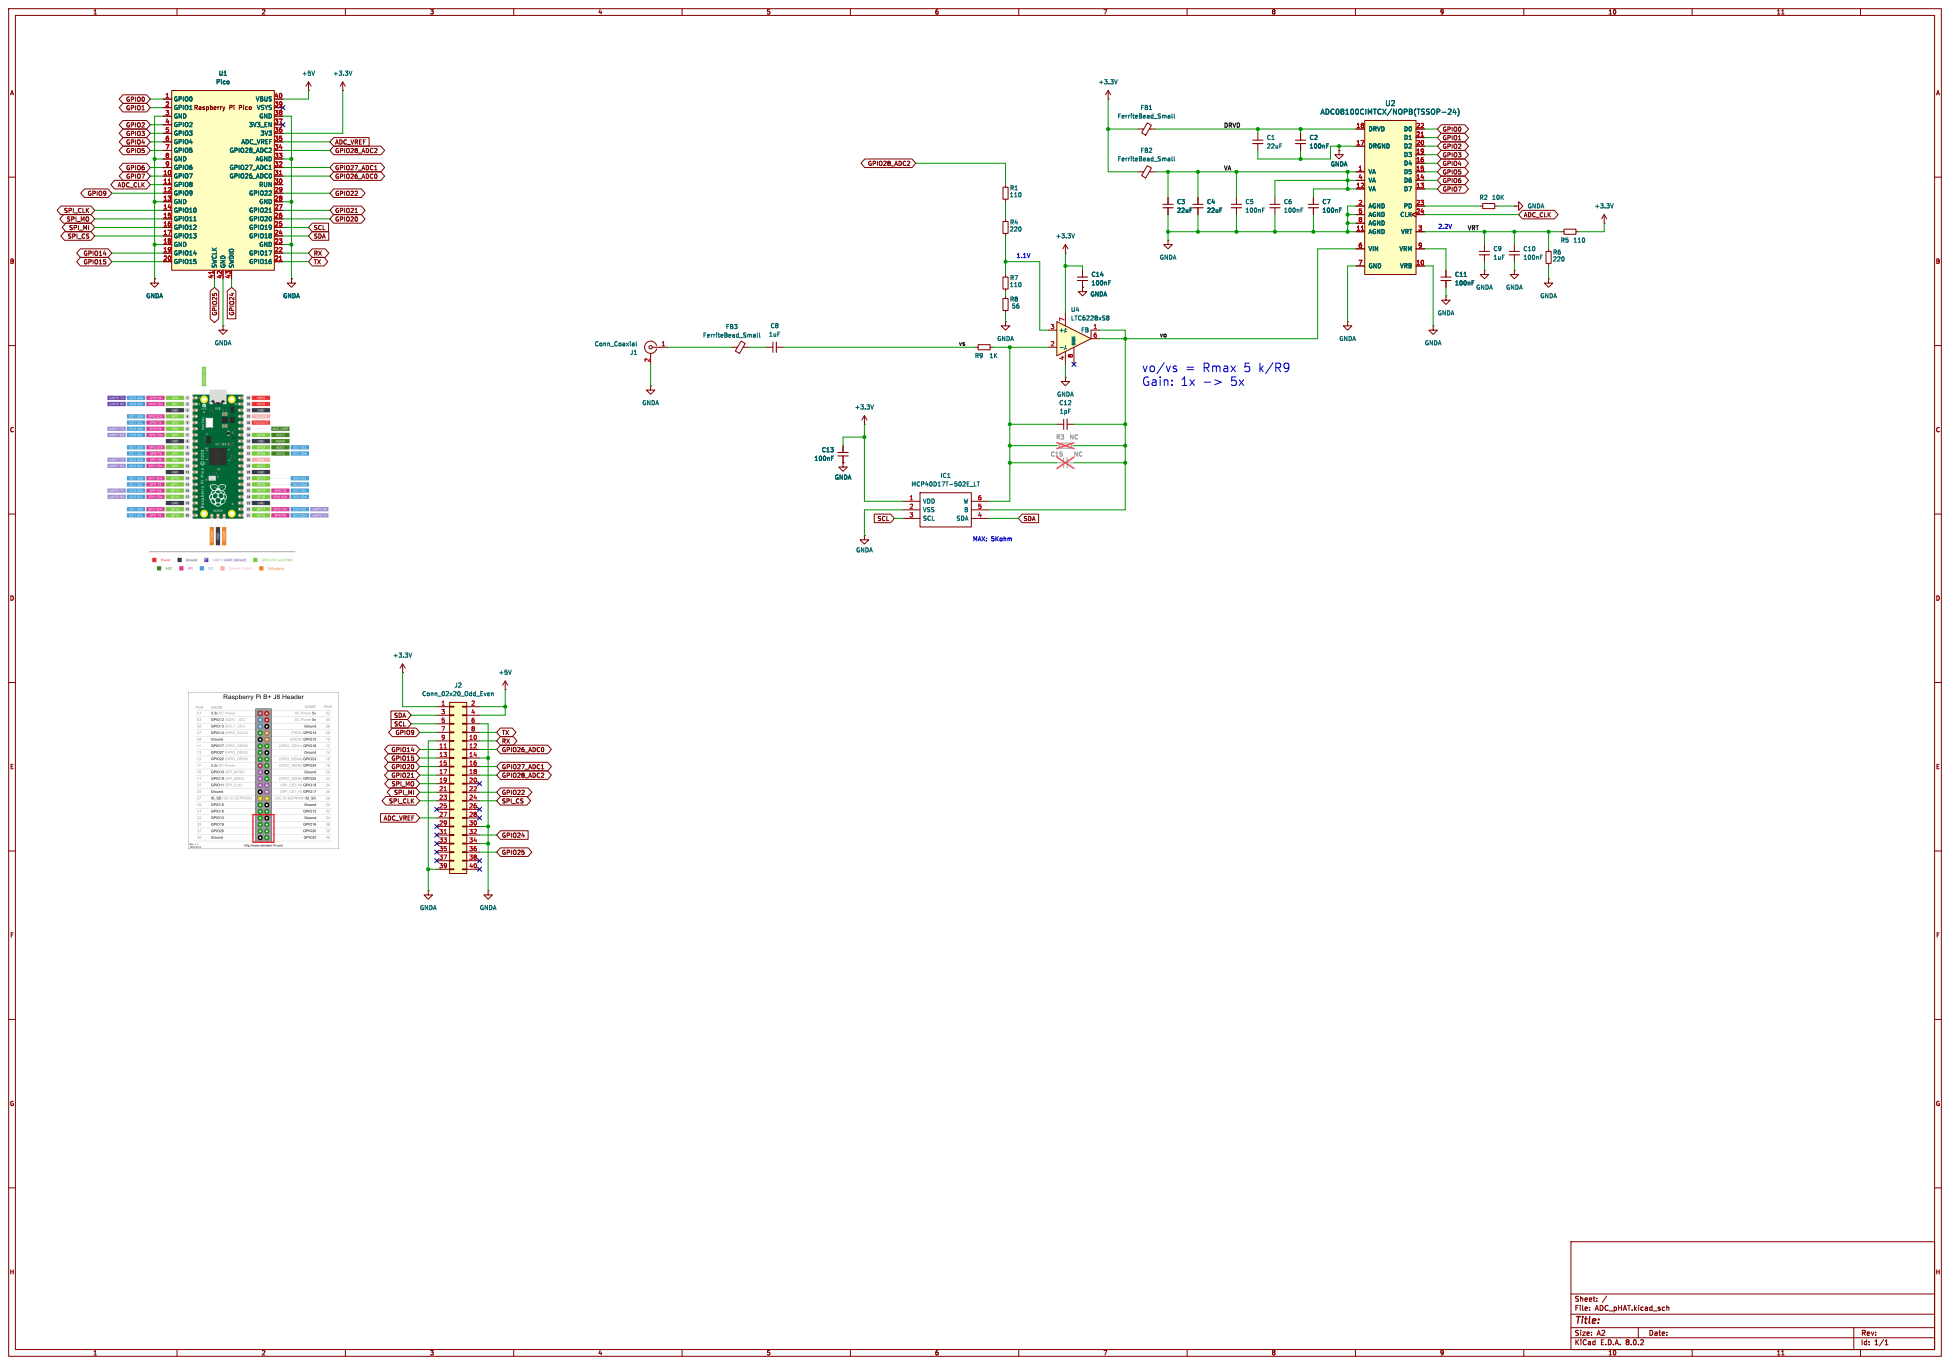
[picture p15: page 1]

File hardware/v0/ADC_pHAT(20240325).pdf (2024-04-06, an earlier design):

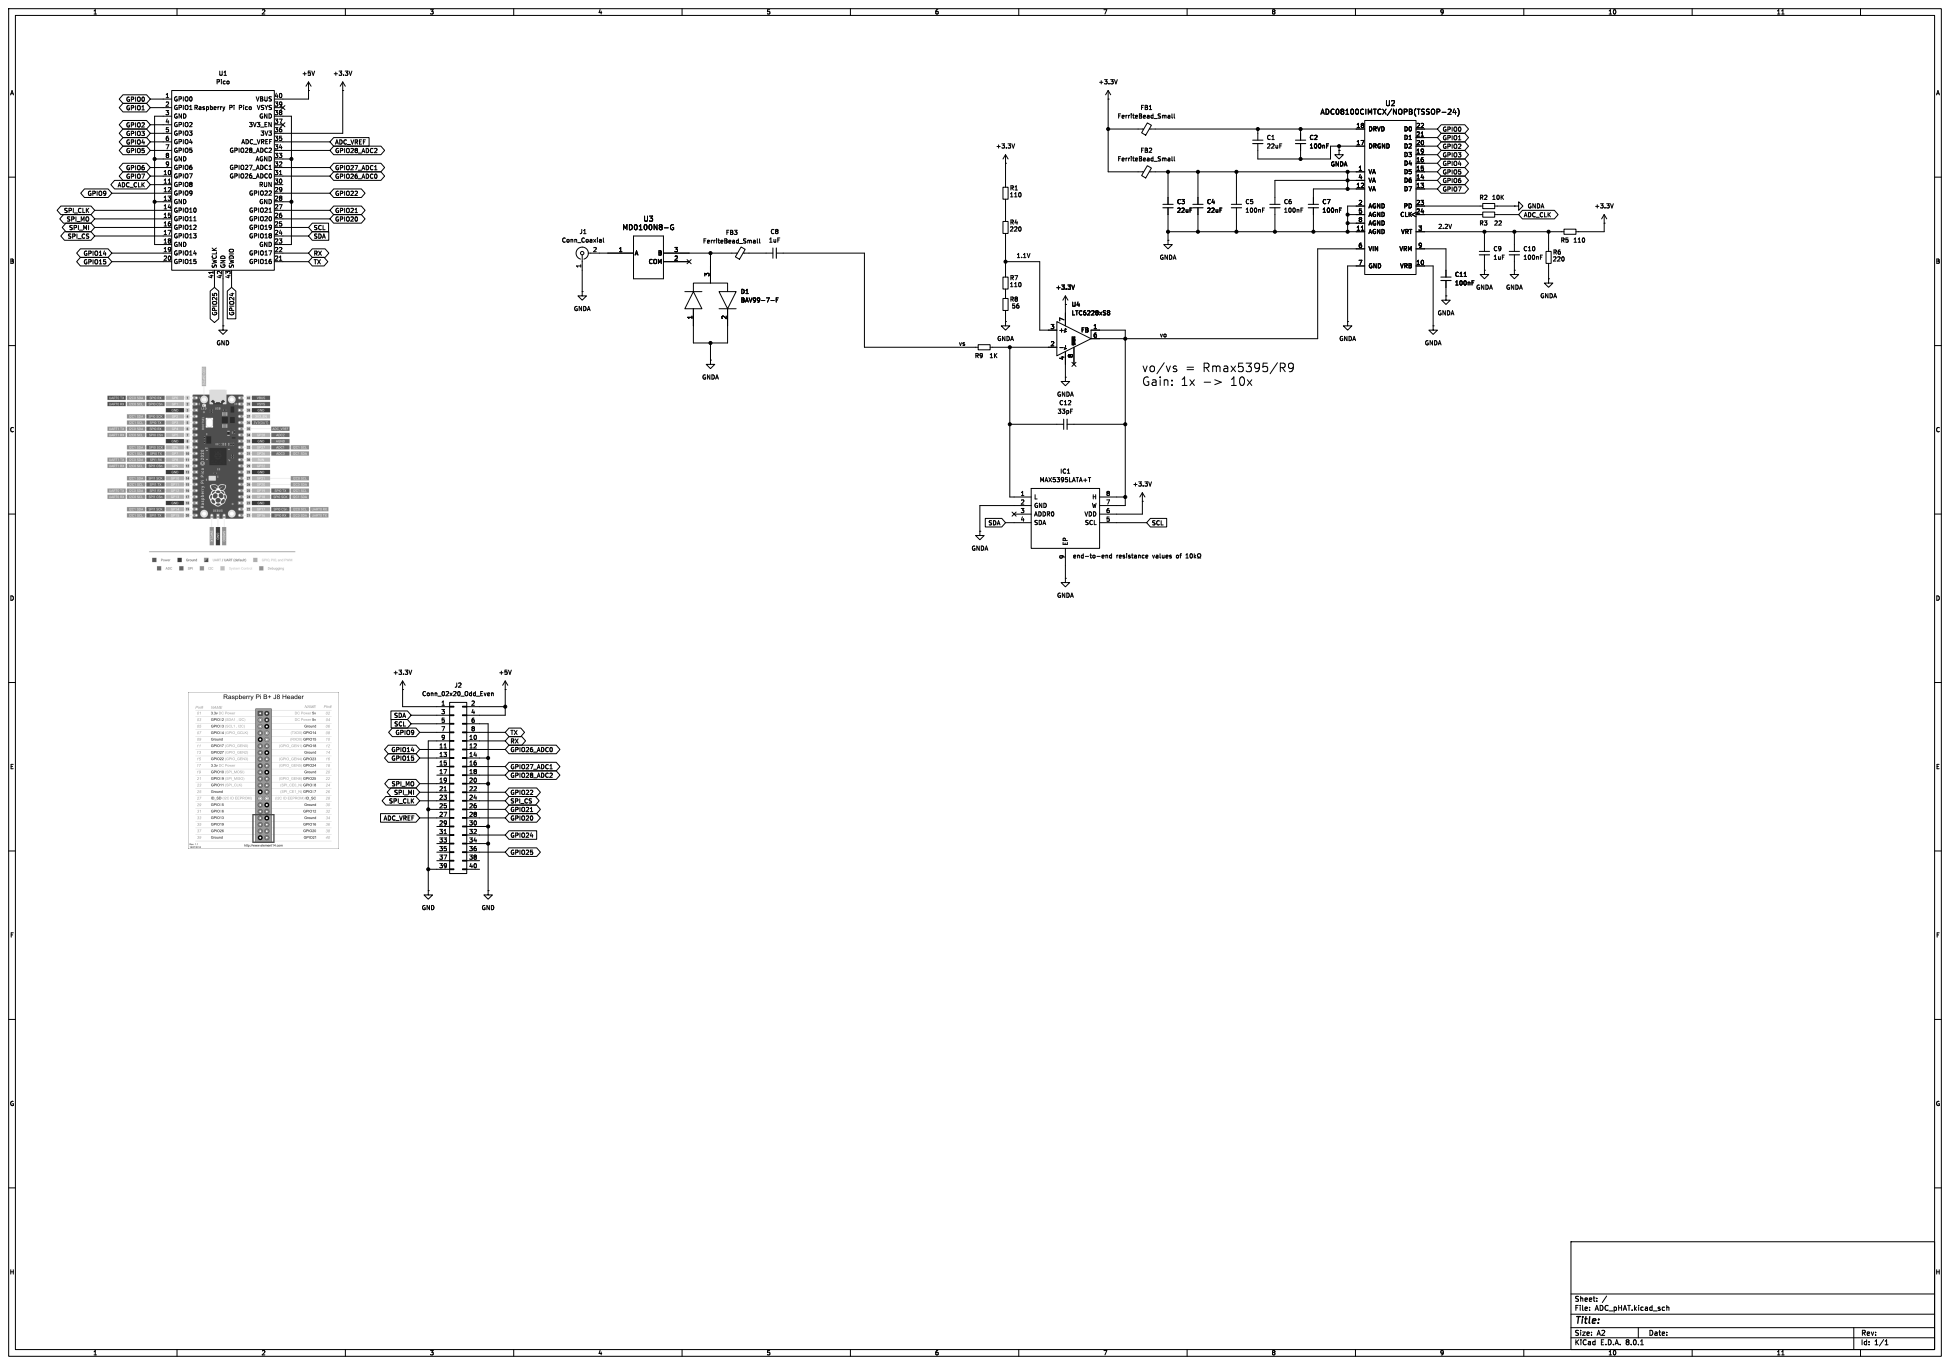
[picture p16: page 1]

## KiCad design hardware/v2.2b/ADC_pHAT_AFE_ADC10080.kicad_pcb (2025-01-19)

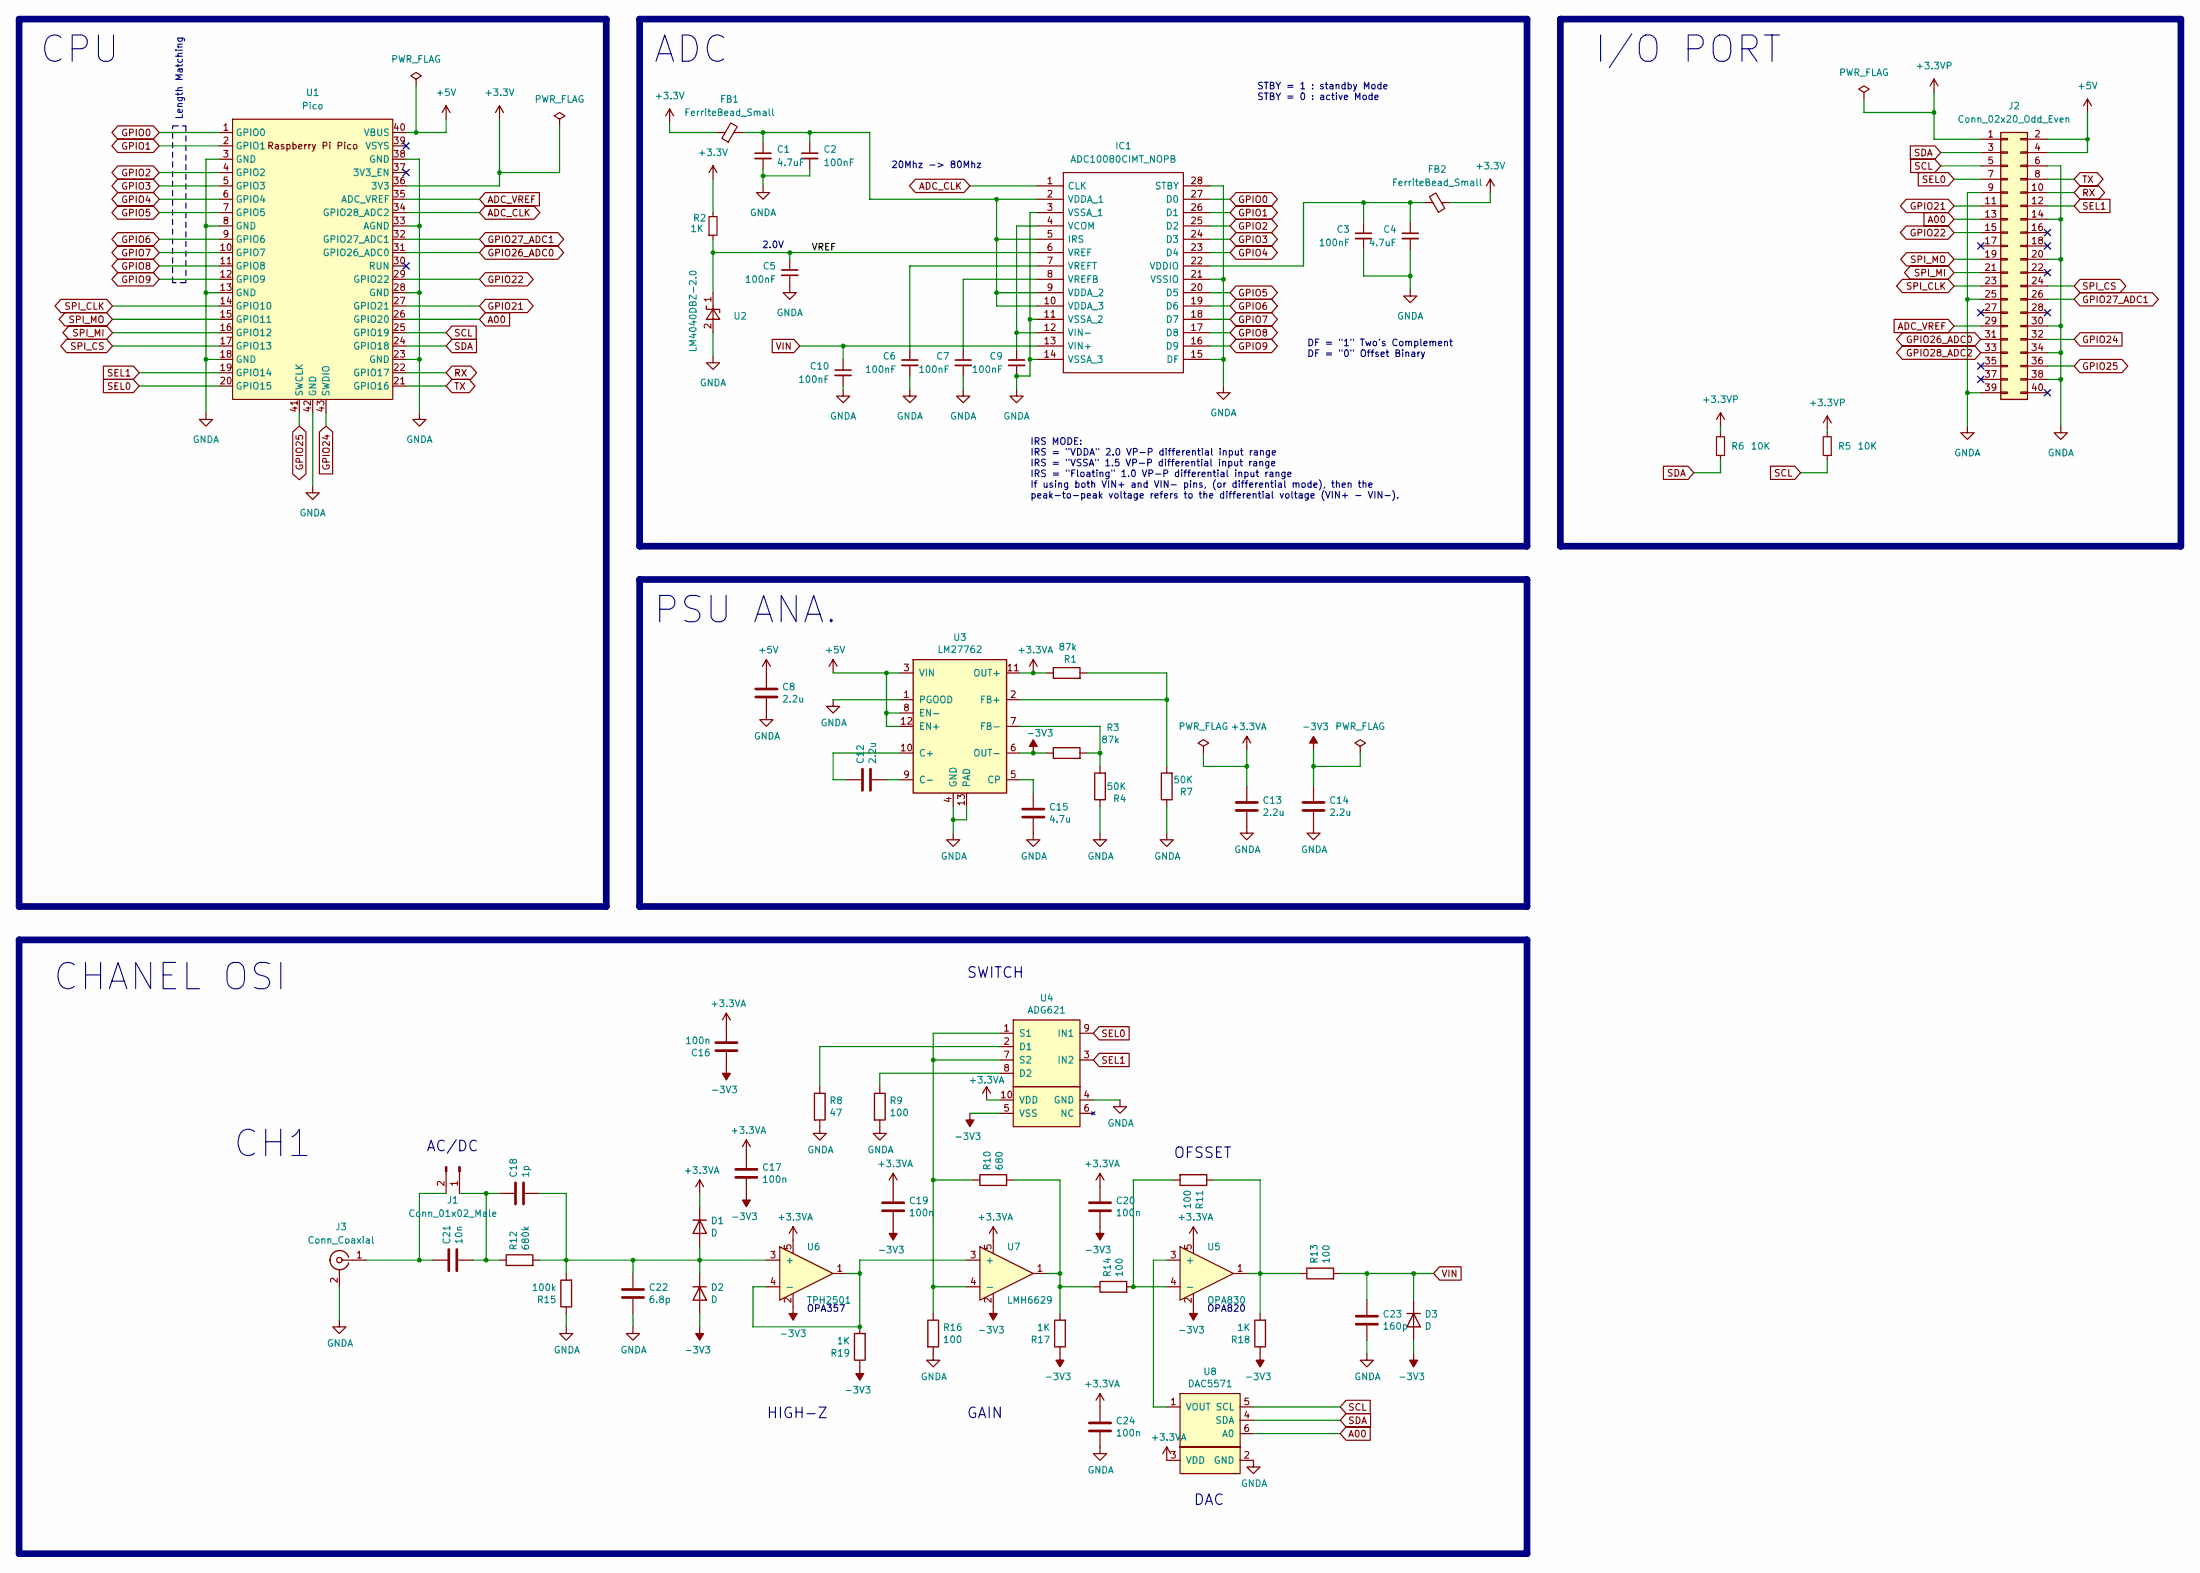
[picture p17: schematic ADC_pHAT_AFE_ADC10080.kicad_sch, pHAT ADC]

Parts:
C1, C4: 4.7uF; R_0603_1608Metric
C2, C3, C5, C6, C7, C9, C10: 100nF; R_0603_1608Metric
C8, C12, C13, C14: 2.2u; C_0603_1608Metric; MFR. Part # CL10A225KO8NNNC; LCSC Part # C23630
C15: 4.7u; C_0603_1608Metric; MFR. Part # CL10A475KO8NNNC; LCSC Part # C19666
C16, C17, C19, C20, C24: 100n; C_0603_1608Metric; MFR. Part # CC0603KRX7R9BB104; LCSC Part # C14663
C18: 1p; C_0603_1608Metric; MFR. Part # CL10C010CB8NNNC; LCSC Part # C23969
C21: 10n; C_0603_1608Metric; MFR. Part # 0603B103K500NT; LCSC Part # C57112
C22: 6.8p; C_0603_1608Metric; MFR. Part # 0603CG6R8C500NT; LCSC Part # C1679
C23: 160p; C_0603_1608Metric; MFR. Part # FN18X104K160PSG; LCSC Part # C235729
D1, D2, D3: D; D_0603_1608Metric
FB1, FB2: FerriteBead_Small; L_1206_3216Metric
IC1: ADC10080CIMT_NOPB; SOP65P640X120-28N; Mouser Part Number 926-ADC10080CIMTNOPB
J1: Conn_01x02_Male; PinHeader_1x02_P1.00mm_Vertical_SMD_Pin1Left
J2: Conn_02x20_Odd_Even; PinSocket_2x20_P2.54mm_Vertical
J3: Conn_Coaxial; AMPHENOL_132357-11-MOD
R1, R3: 87k; R_0603_1608Metric; MFR. Part # 0603WAF8202T5E; LCSC Part # C23254
R2: 1K; R_0603_1608Metric
R4, R7: 50K; R_0603_1608Metric; MFR. Part # 0603WAF1503T5E; LCSC Part # C22807
R5, R6: 10K; R_0603_1608Metric
R8: 47; R_1206_3216Metric; MFR. Part # 0603WAF470JT5E; LCSC Part # C23182
R9, R16: 100; R_1206_3216Metric; MFR. Part # 0603WAF1000T5E; LCSC Part # C22775
R10: 680; R_0603_1608Metric; MFR. Part # 0603WAF6801T5E; LCSC Part # C23212
R11, R13, R14: 100; R_0603_1608Metric; MFR. Part # 0603WAF1000T5E; LCSC Part # C22775
R12: 680k; R_0603_1608Metric; MFR. Part # 0603WAF6803T5E; LCSC Part # C25822
R15: 100k; R_0603_1608Metric; MFR. Part # 0603WAF1003T5E; LCSC Part # C25803
R17, R18, R19: 1K; R_0603_1608Metric; MFR. Part # 0603WAF1001T5E; LCSC Part # C21190
U1: Pico; RPi_Pico_SMD
U2: LM4040DBZ-2.0; SOT-23
U3: LM27762; WSON-12-1EP_3x2mm_P0.5mm_EP1x2.65_ThermalVias; MFR. Part # LM27762DSSR; LCSC Part # C473398
U4: ADG621; MSOP-10_3x3mm_P0.5mm; LCSC Part # C208597
U5: OPA830; SOT-23-5; LCSC Part # C181539
U6: TPH2501; SOT-23-5; LCSC Part # C139385
U7: LMH6629; SOT-23-5; LCSC Part # C206003
U8: DAC5571; SOT-23-6; LCSC Part # C24061

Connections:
+3.3V: FB1.1, FB2.1, R2.2, U1.36 (3V3)
+3.3VA: C13.1, C16.2, C17.1, C19.1, C20.1, C24.1, D1.1 (K), R1.1, U3.11 (OUT+), U4.10 (VDD), U5.5, U6.5, U7.5, U8.3 (VDD)
+3.3VP: J2.1, R5.2, R6.2
+5V: C8.1, J2.2, J2.4, U1.40 (VBUS), U3.3 (VIN), U3.8 (EN-), U3.12 (EN+)
-3V3: C14.1, C16.1, C17.2, C19.2, C20.2, D2.2 (A), D3.2 (A), R3.1, R17.1, R18.1, R19.1, U3.6 (OUT-), U4.5 (VSS), U5.2, U6.2, U7.2
/VREF: C5.1, IC1.6 (VREF), R2.1, U2.1 (K)
A00: J2.13, U1.26 (GPIO20), U8.6 (A0)
ADC_CLK: IC1.1 (CLK), U1.34 (GPIO28_ADC2)
ADC_VREF: J2.29, U1.35 (ADC_VREF)
GNDA: C1.2, C2.2, C3.2, C4.2, C5.2, C6.2, C7.2, C8.2, C9.2, C10.2, C13.2, C14.2, C15.2, C22.2, C23.2, C24.2, IC1.3 (VSSA_1), IC1.11 (VSSA_2), IC1.14 (VSSA_3), IC1.15 (DF), IC1.21 (VSSIO), IC1.28 (STBY), J2.6, J2.9, J2.14, J2.20, J2.25, J2.30, J2.34, J2.38, J2.39, J3.2 (Ext), R4.1, R7.1, R8.2, R9.2, R15.1, R16.2, U1.3 (GND), U1.8 (GND), U1.13 (GND), U1.18 (GND), U1.23 (GND), U1.28 (GND), U1.33 (AGND), U1.38 (GND), U1.42 (GND), U2.2 (A), U3.1 (PGOOD), U3.4 (GND), U3.13 (PAD), U4.4 (GND), U8.2 (GND)
GPIO0: IC1.27 (D0), U1.1 (GPIO0)
GPIO1: IC1.26 (D1), U1.2 (GPIO1)
GPIO2: IC1.25 (D2), U1.4 (GPIO2)
GPIO3: IC1.24 (D3), U1.5 (GPIO3)
GPIO4: IC1.23 (D4), U1.6 (GPIO4)
GPIO5: IC1.20 (D5), U1.7 (GPIO5)
GPIO6: IC1.19 (D6), U1.9 (GPIO6)
GPIO7: IC1.18 (D7), U1.10 (GPIO7)
GPIO8: IC1.17 (D8), U1.11 (GPIO8)
GPIO9: IC1.16 (D9), U1.12 (GPIO9)
GPIO21: J2.11, U1.27 (GPIO21)
GPIO22: J2.15, U1.29 (GPIO22)
GPIO24: J2.32, U1.43 (SWDIO)
GPIO25: J2.36, U1.41 (SWCLK)
GPIO26_ADC0: J2.31, U1.31 (GPIO26_ADC0)
GPIO27_ADC1: J2.26, U1.32 (GPIO27_ADC1)
GPIO28_ADC2: J2.33
unnamed: C18.2, C22.1, D1.2 (A), D2.1 (K), R12.2, R15.2, U6.3 (+)
unnamed: C1.1, C2.1, FB1.2, IC1.2 (VDDA_1), IC1.5 (IRS), IC1.9 (VDDA_2), IC1.10 (VDDA_3)
unnamed: C9.1, IC1.4 (VCOM), IC1.12 (VIN-)
unnamed: C3.1, C4.1, FB2.2, IC1.22 (VDDIO)
unnamed: C7.1, IC1.8 (VREFB)
unnamed: C6.1, IC1.7 (VREFT)
unnamed: C18.1, C21.2, J1.1, R12.1
unnamed: C21.1, J1.2, J3.1 (In)
unnamed: R10.2, R14.1, R17.2, U7.1
unnamed: R11.1, R13.1, R18.2, U5.1
unnamed: C12.1, U3.10 (C+)
unnamed: C12.2, U3.9 (C-)
unnamed: C15.1, U3.5 (CP)
unnamed: R1.2, R7.2, U3.2 (FB+)
unnamed: R3.2, R4.2, U3.7 (FB-)
unnamed: R8.1, U4.2 (D1)
unnamed: R9.1, U4.8 (D2)
unnamed: R10.1, R16.1, U4.1 (S1), U4.7 (S2), U7.4 (-)
unnamed: U5.3 (+), U8.1 (VOUT)
unnamed: R11.2, R14.2, U5.4 (-)
unnamed: R19.2, U6.1, U6.4 (-), U7.3 (+)
RX: J2.10, U1.22 (GPIO17)
SCL: J2.5, R5.1, U1.25 (GPIO19), U8.5 (SCL)
SDA: J2.3, R6.1, U1.24 (GPIO18), U8.4 (SDA)
SEL0: J2.7, U1.20 (GPIO15), U4.9 (IN1)
SEL1: J2.12, U1.19 (GPIO14), U4.3 (IN2)
SPI_CLK: J2.23, U1.14 (GPIO10)
SPI_CS: J2.24, U1.17 (GPIO13)
SPI_MI: J2.21, U1.16 (GPIO12)
SPI_MO: J2.19, U1.15 (GPIO11)
TX: J2.8, U1.21 (GPIO16)
VIN: C10.1, C23.1, D3.1 (K), IC1.13 (VIN+), R13.2

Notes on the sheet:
CHANEL OSI
IRS MODE: IRS = "VDDA" 2.0 VP-P differential input range IRS = "VSSA" 1.5 VP-P differential input range IRS = "Floating" 1.0 VP-P differential input range If using both VIN+ and VIN- pins, (or differential mode), then the peak-to-peak voltage refers to the differential voltage (VIN+ - VIN-).
AC/DC
DAC
CPU
OPA820
PSU ANA.
I/O PORT
GAIN
STBY = 1 : standby Mode STBY = 0 : active Mode
20Mhz -> 80Mhz
ADC
2.0V
OPA357
Length Matching
SWITCH
DF = "1" Two's Complement DF = "0" Offset Binary
HIGH-Z
OFSSET
CH1

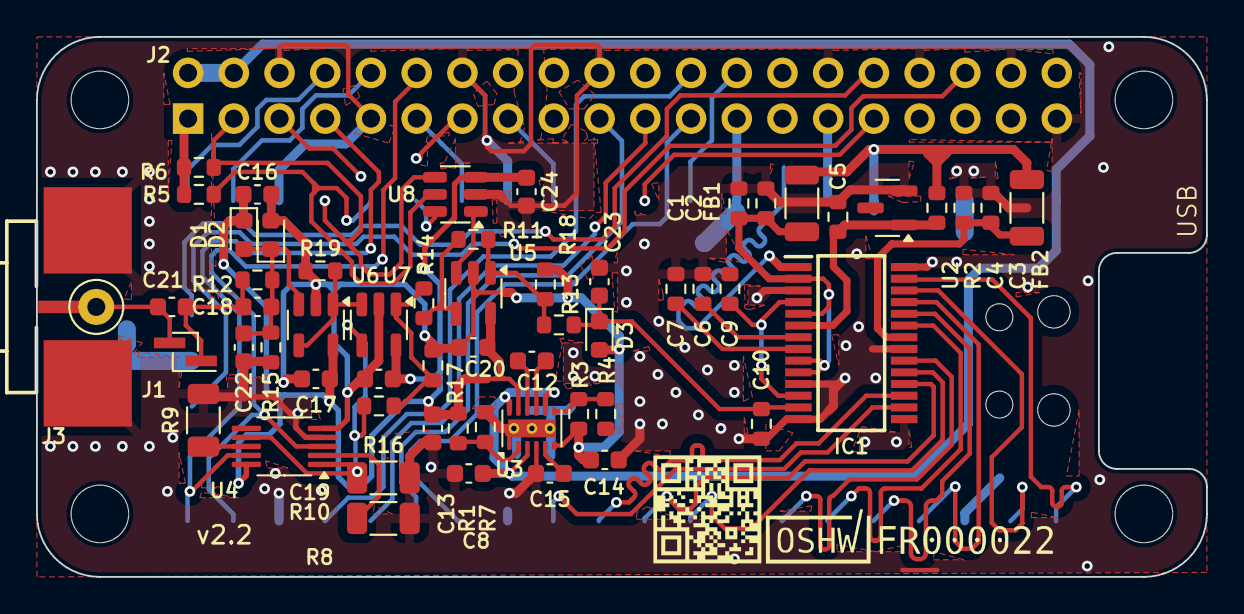
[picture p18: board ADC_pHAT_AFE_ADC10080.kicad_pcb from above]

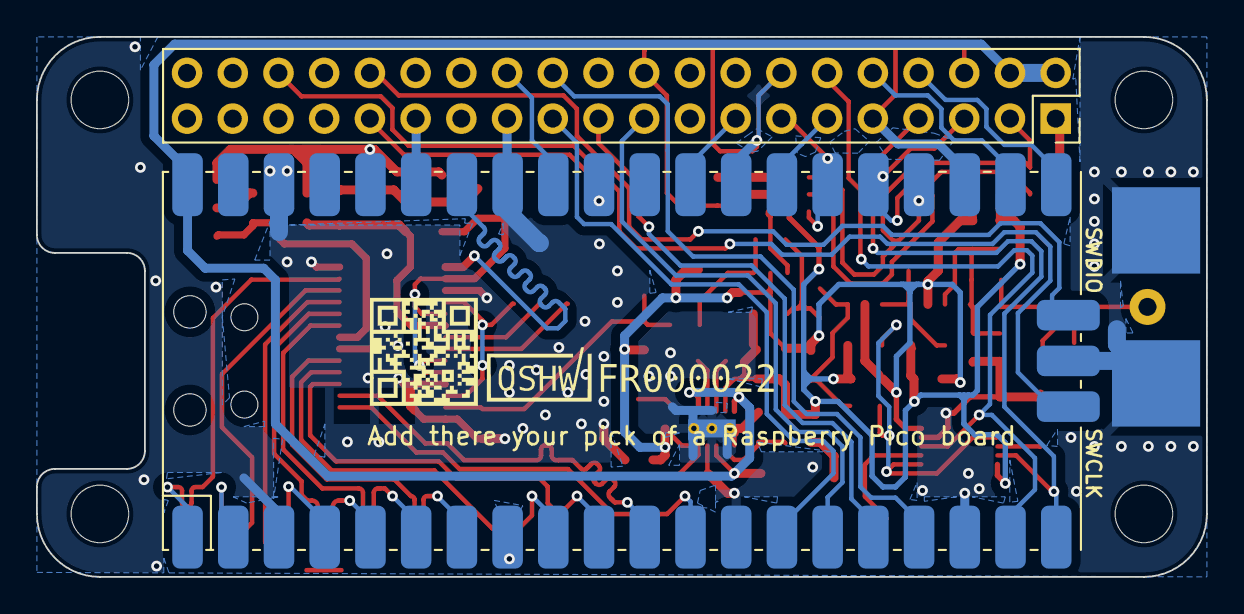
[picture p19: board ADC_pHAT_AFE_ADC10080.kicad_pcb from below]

Board: 2 copper layers, 65.0 x 30.0 mm, 59 parts (2 on the bottom side), 58 nets.

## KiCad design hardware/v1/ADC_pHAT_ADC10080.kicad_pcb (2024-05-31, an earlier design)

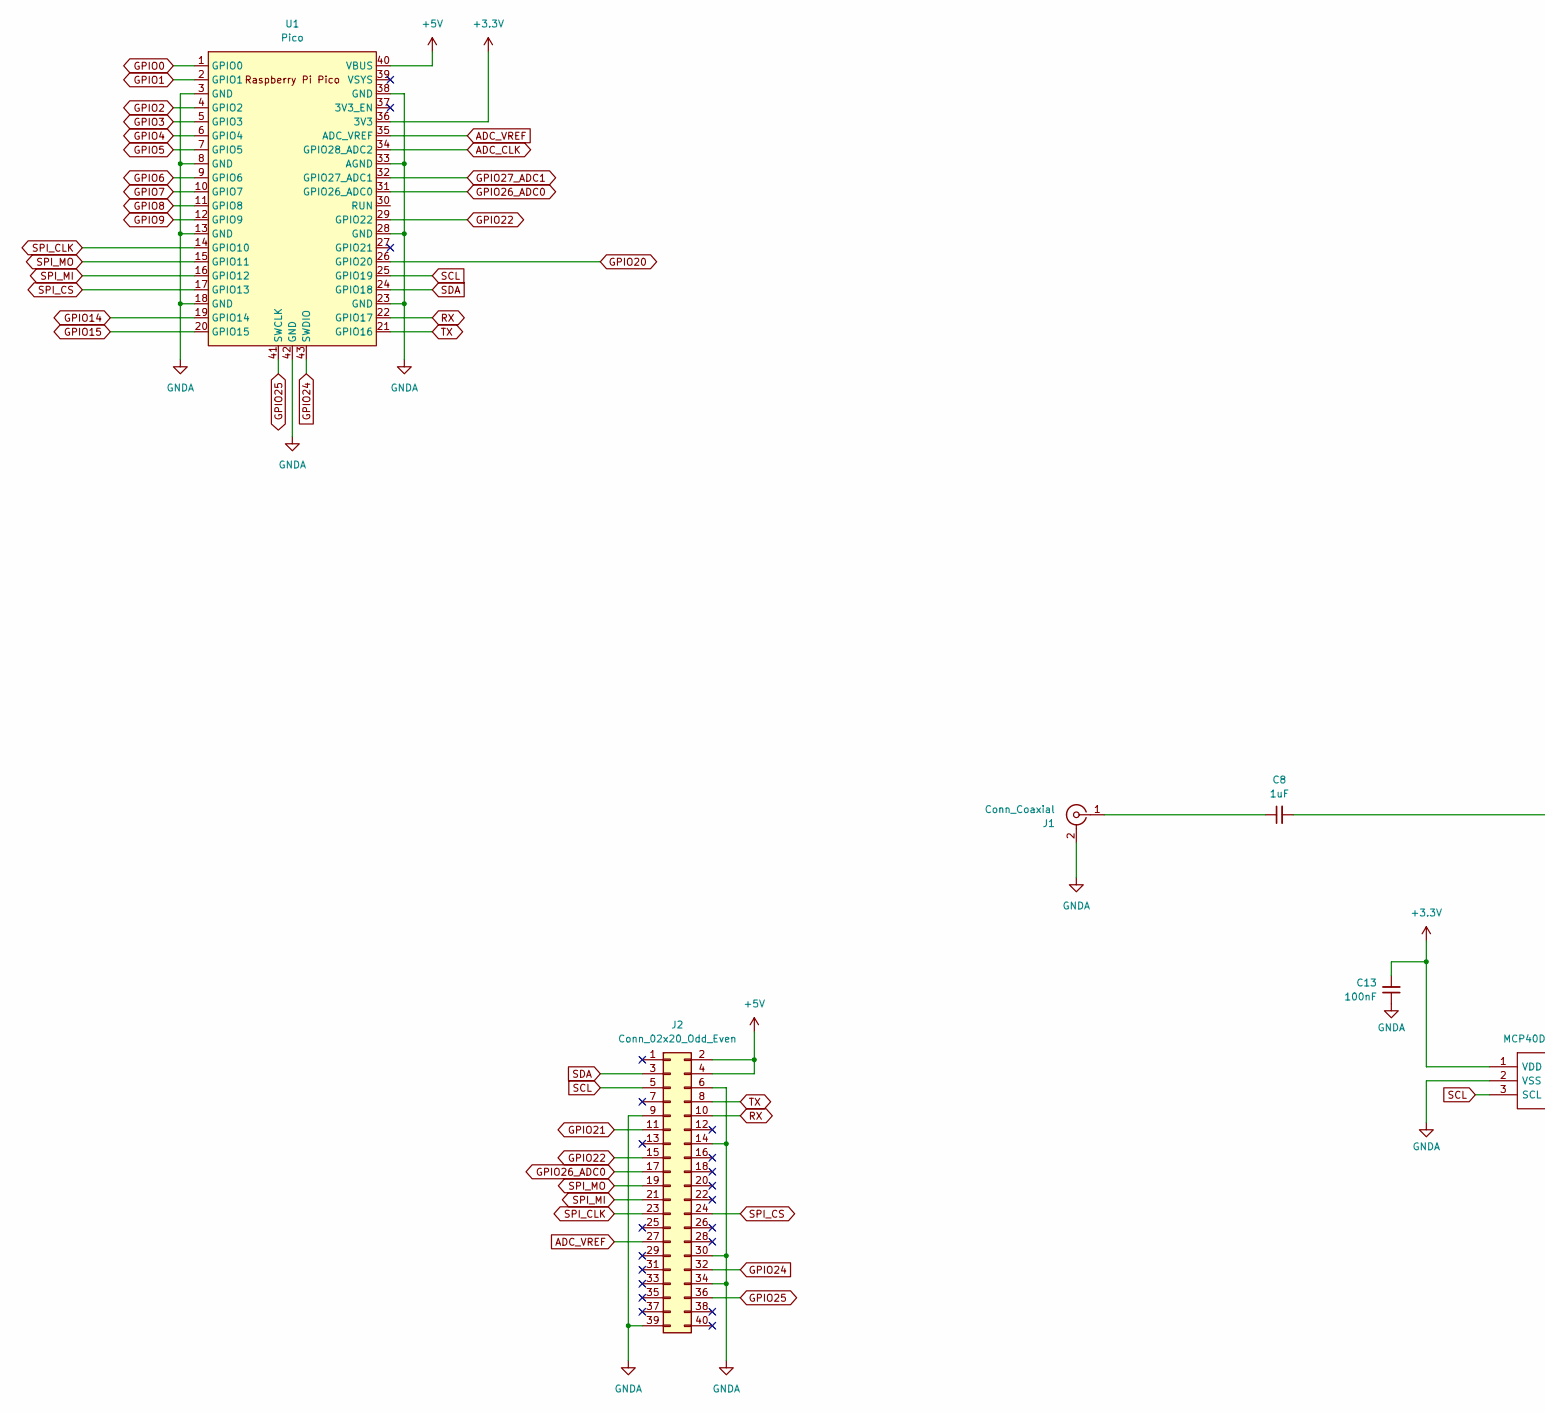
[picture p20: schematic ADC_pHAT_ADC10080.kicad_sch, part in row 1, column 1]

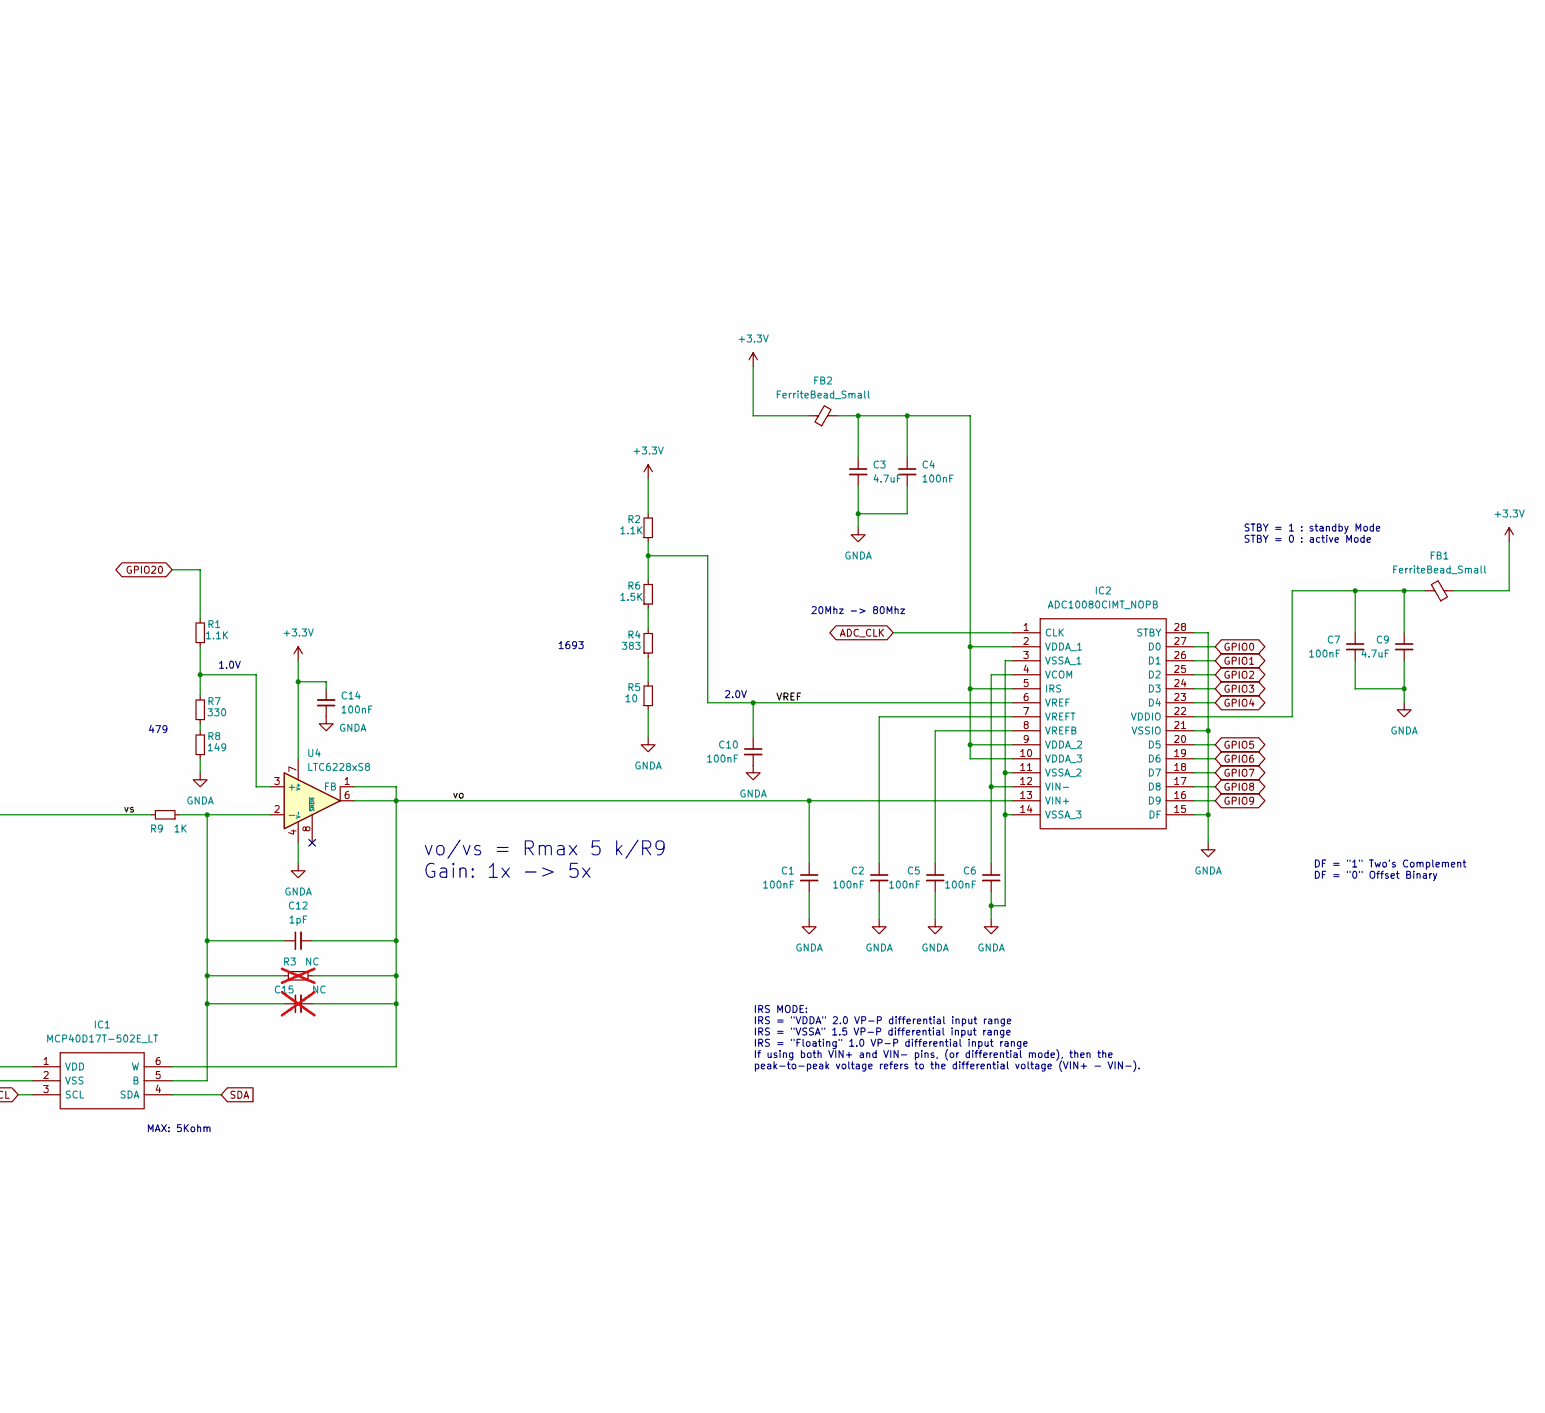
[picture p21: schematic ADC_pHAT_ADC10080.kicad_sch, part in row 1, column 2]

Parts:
C1, C2, C4, C5, C6, C7, C10, C13, C14: 100nF; C_1206_3216Metric
C3, C9: 4.7uF; C_1206_3216Metric
C8: 1uF; C_1206_3216Metric
C12: 1pF; C_1206_3216Metric
C15: NC; C_1206_3216Metric; not fitted
FB1, FB2: FerriteBead_Small; L_1206_3216Metric
IC1: MCP40D17T-502E_LT; SOT65P210X110-6N; Mouser Part Number 579-MCP40D17T502E/LT
IC2: ADC10080CIMT_NOPB; SOP65P640X120-28N; Mouser Part Number 926-ADC10080CIMTNOPB
J1: Conn_Coaxial; AMPHENOL_132357-11
J2: Conn_02x20_Odd_Even; PinSocket_2x20_P2.54mm_Vertical
R1, R2: 1.1K; R_1206_3216Metric
R3: NC; R_1206_3216Metric; not fitted
R4: 383; R_1206_3216Metric
R5: 10; R_1206_3216Metric
R6: 1.5K; R_1206_3216Metric
R7: 330; R_1206_3216Metric
R8: 149; R_1206_3216Metric
R9: 1K; R_1206_3216Metric
U1: Pico; RPi_Pico_SMD
U4: LTC6228xS8; SO-8_3.9x4.9mm_P1.27mm

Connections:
+3.3V: C13.2, C14.2, FB1.1, FB2.1, IC1.1 (VDD), R2.2, U1.36 (3V3), U4.7 (V+)
+5V: J2.2, J2.4, U1.40 (VBUS)
/VREF: C10.1, IC2.6 (VREF), R2.1, R6.2
/vo: C1.1, C12.2, C15.2, IC1.6 (W), IC2.13 (VIN+), R3.1, U4.1 (FB), U4.6
/vs: C8.2, R9.2
ADC_CLK: IC2.1 (CLK), U1.34 (GPIO28_ADC2)
ADC_VREF: J2.27, U1.35 (ADC_VREF)
GNDA: C1.2, C2.2, C3.2, C4.2, C5.2, C6.2, C7.2, C9.2, C10.2, C13.1, C14.1, IC1.2 (VSS), IC2.3 (VSSA_1), IC2.11 (VSSA_2), IC2.14 (VSSA_3), IC2.15 (DF), IC2.21 (VSSIO), IC2.28 (STBY), J1.2 (Ext), J2.6, J2.9, J2.14, J2.30, J2.34, J2.39, R5.1, R8.1, U1.3 (GND), U1.8 (GND), U1.13 (GND), U1.18 (GND), U1.23 (GND), U1.28 (GND), U1.33 (AGND), U1.38 (GND), U1.42 (GND), U4.4 (V-), U4.5 (V-)
GPIO0: IC2.27 (D0), U1.1 (GPIO0)
GPIO1: IC2.26 (D1), U1.2 (GPIO1)
GPIO2: IC2.25 (D2), U1.4 (GPIO2)
GPIO3: IC2.24 (D3), U1.5 (GPIO3)
GPIO4: IC2.23 (D4), U1.6 (GPIO4)
GPIO5: IC2.20 (D5), U1.7 (GPIO5)
GPIO6: IC2.19 (D6), U1.9 (GPIO6)
GPIO7: IC2.18 (D7), U1.10 (GPIO7)
GPIO8: IC2.17 (D8), U1.11 (GPIO8)
GPIO9: IC2.16 (D9), U1.12 (GPIO9)
GPIO14: U1.19 (GPIO14)
GPIO15: U1.20 (GPIO15)
GPIO20: R1.2, U1.26 (GPIO20)
GPIO21: J2.11
GPIO22: J2.15, U1.29 (GPIO22)
GPIO24: J2.32, U1.43 (SWDIO)
GPIO25: J2.36, U1.41 (SWCLK)
GPIO26_ADC0: J2.17, U1.31 (GPIO26_ADC0)
GPIO27_ADC1: U1.32 (GPIO27_ADC1)
unnamed: C12.1, C15.1, IC1.5 (B), R3.2, R9.1, U4.2 (-)
unnamed: C3.1, C4.1, FB2.2, IC2.2 (VDDA_1), IC2.5 (IRS), IC2.9 (VDDA_2), IC2.10 (VDDA_3)
unnamed: C6.1, IC2.4 (VCOM), IC2.12 (VIN-)
unnamed: C7.1, C9.1, FB1.2, IC2.22 (VDDIO)
unnamed: C5.1, IC2.8 (VREFB)
unnamed: C2.1, IC2.7 (VREFT)
unnamed: C8.1, J1.1 (In)
unnamed: R4.1, R5.2
unnamed: R4.2, R6.1
unnamed: R7.1, R8.2
unnamed: R1.1, R7.2, U4.3 (+)
RX: J2.10, U1.22 (GPIO17)
SCL: IC1.3 (SCL), J2.5, U1.25 (GPIO19)
SDA: IC1.4 (SDA), J2.3, U1.24 (GPIO18)
SPI_CLK: J2.23, U1.14 (GPIO10)
SPI_CS: J2.24, U1.17 (GPIO13)
SPI_MI: J2.21, U1.16 (GPIO12)
SPI_MO: J2.19, U1.15 (GPIO11)
TX: J2.8, U1.21 (GPIO16)

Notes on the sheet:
STBY = 1 : standby Mode STBY = 0 : active Mode
DF = "1" Two's Complement DF = "0" Offset Binary
1693
479
20Mhz -> 80Mhz
MAX: 5Kohm
IRS MODE: IRS = "VDDA" 2.0 VP-P differential input range IRS = "VSSA" 1.5 VP-P differential input range IRS = "Floating" 1.0 VP-P differential input range If using both VIN+ and VIN- pins, (or differential mode), then the peak-to-peak voltage refers to the differential voltage (VIN+ - VIN-).
vo/vs = Rmax 5 k/R9 Gain: 1x -> 5x
2.0V
1.0V

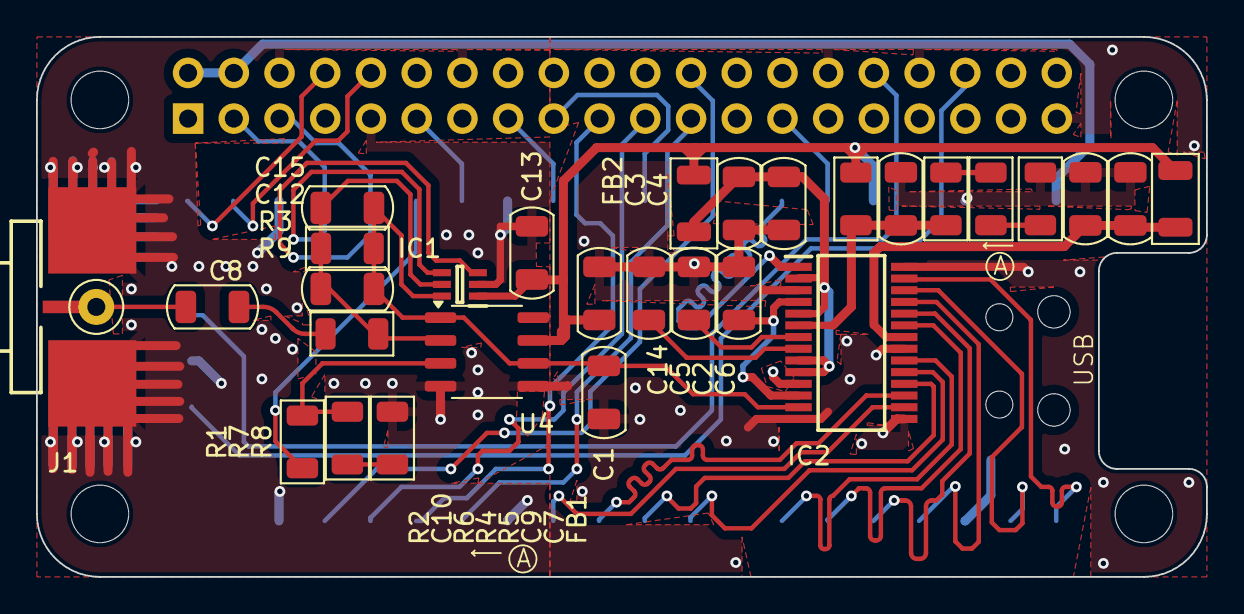
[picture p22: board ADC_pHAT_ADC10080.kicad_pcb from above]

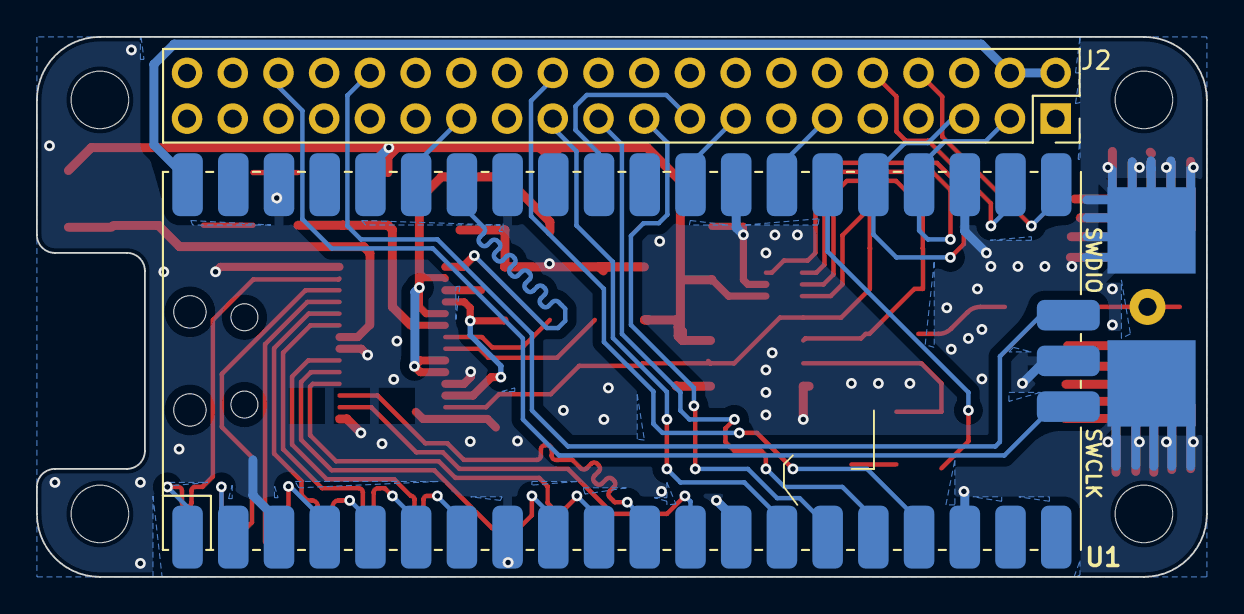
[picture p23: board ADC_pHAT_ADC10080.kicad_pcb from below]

Board: 2 copper layers, 65.0 x 30.0 mm, 31 parts (2 on the bottom side), 42 nets.

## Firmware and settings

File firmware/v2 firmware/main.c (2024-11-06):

//!
//! \file       main.c
//! \author     Abdelrahman Ali
//! \date       2024-09-08
//!
//! \brief      adc i2c main entry.
//!

//---------------------------------------------------------------------------
// INCLUDES
//--------------------------------------------------------------------------
#include "adc/adc.h"
#include "i2c/i2c.h"

//---------------------------------------------------------------------------
// MAIN FUNCTION
//---------------------------------------------------------------------------

int main()
{
    stdio_init_all();
    sleep_ms(100);
    pio_i2c_init();
    sleep_ms(100);
    pio_adc_init();
    sleep_ms(100);
    while (1)
    {
        i2c_trigger();
        sleep_ms(100);
        adc_trigger();
        sleep_ms(100);
    }
}

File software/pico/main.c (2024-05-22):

//!
//! \file       main.c
//!
//! \brief      ADC software for the 0xA5EDED board
//!

//---------------------------------------------------------------------------
// INCLUDES
//--------------------------------------------------------------------------
#include "adc/adc.h"

//---------------------------------------------------------------------------
// MAIN FUNCTION
//---------------------------------------------------------------------------

int main()
{
    stdio_init_all();
    sleep_ms(10);
    set_sys_clock_khz(250000, true);
    pio_adc_init();
    while (true)
    {
        adc();
        sleep_ms(100);
    }
}

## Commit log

2024-04-06 First release of the pHAT
    [ADC_pHAT-B_Cu.gbr, ADC_pHAT-B_Mask.gbr, ADC_pHAT-B_Paste.gbr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]
2024-12-01 v2.2 updates
    [ADC_pHAT_AFE_ADC10080-B_Cu.gbr, ADC_pHAT_AFE_ADC10080-B_Mask.gbr, ADC_pHAT_AFE_ADC10080-B_Paste.gbr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]
